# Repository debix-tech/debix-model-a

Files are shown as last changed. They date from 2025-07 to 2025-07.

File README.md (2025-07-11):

# DEBIX Model A Industrial Single Board Computer

<p align="center">
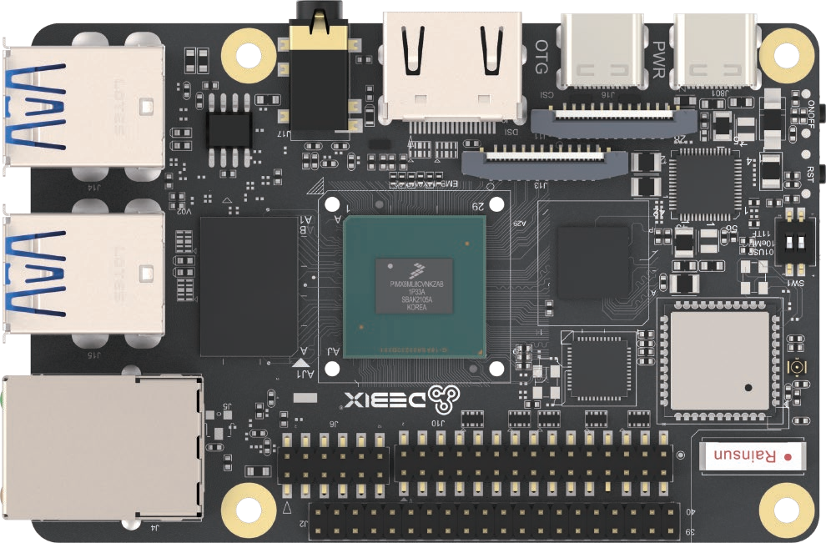
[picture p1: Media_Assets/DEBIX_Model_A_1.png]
DEBIX Model A(1)

</p>

## Overview
DEBIX Model A is an industrial-grade single board computer to bring you faster speed and more powerful performance. Powered by quad core i.MX 8M Plus with 2.3 TOPS NPU, DEBIX Model A with complete software development and rich I/O ports is ready and capable for direct applications in industry 4.0, IoT, smart city, and multimedia.

## Main Features
- **Powerful Performance**  
  Built for demanding industrial applications, DEBIX Model A boasts a quad-core ARM Cortex-A53 CPU up to 1.8GHz and 2GB/4GB/8GB LPDDR4 RAM. This combination ensures smooth operation even for complex processing tasks.
- **Industrial Grade Build**  
  Designed for harsh environments, DEBIX Model A features industrial-grade components and a wide CPU temperature range of -40°C to 105°C. Its DDR inline ECC design and 14 FinFET process further enhance its reliability.
- **Rich Connectivity**  
  DEBIX Model A offers a comprehensive range of connectivity options, including Gigabit Ethernet, 2.4GHz & 5GHz Wi-Fi, Bluetooth 5.0, high-speed USB 3.0, and PCIe support. This allows for easy connection and control of various industrial peripherals.
- **Advanced Multimedia**  
  For multimedia applications, DEBIX Model A features 1080p60 video encode and decode (including H.265 and H.264), 3D/2D graphic acceleration, and multiple audio and voice functionalities.
- **Software Support**  
  It includes Android 11/ Yocto-L6.6.36/ Ubuntu 22.04/ Debian 12/ Windows 10 IoT Enterprise/ OpenWRT/ FreeRTOS operating system and basic software for fast and direct applications.

<p align="center">
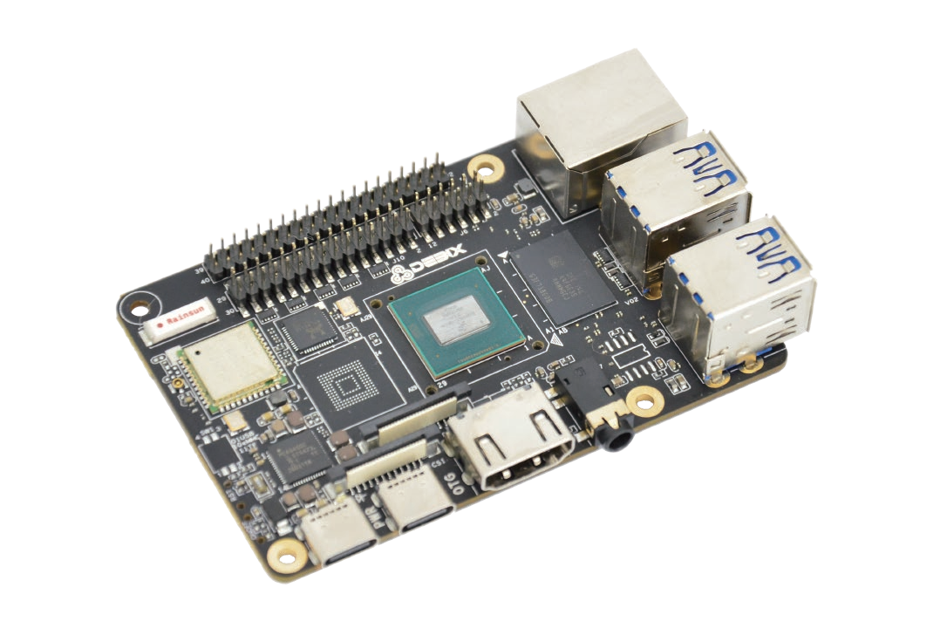
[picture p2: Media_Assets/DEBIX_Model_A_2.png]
DEBIX Model A(2)

</p>

## Specification
| System | |
|---|---|
| CPU | NXP i.MX 8M Plus (default), 4 x ARM Cortex-A53, comes with an integrated neural processing unit (NPU) that delivers up to 2.3 TOPS. Industrial grade CPU runs at 1.6GHz, and commercial grade CPU runs at up to 1.8GHz.(i.MX 8M Plus series CPU optional) |
| Memory | 2GB LPDDR4 (1GB/4GB/8GB optional) |
| Storage | Micro SD card (Onboard 8GB/16GB/32GB/64GB/128GB/256GB eMMC optional) |
| OS | Android 11, Yocto-L6.6.36, Ubuntu 22.04, Debian 12, Win10 IoT Enterprise (also supports OpenWRT and FreeRTOS)<br>*Note: 4GB/8GB RAM required for Win10 IoT, and 8GB RAM is recommended* |
|**I/O Interface**| 
| Gigabit Ethernet| 1 x Gigabit Ethernet, supports TSN and POE power supply (need POE power device module)<br>1 x Gigabit Ethernet via 12pin header (without network transformer) |
| WiFi & BT | 2.4GHz & 5GHz Wi-Fi5, Bluetooth 5.0 |
| USB | 4 x USB 3.0 Host, 1 x USB 2.0 OTG |
| Audio | 1 x Headphone and Mic combo port |
| HDMI | 1 x HDMI OUT |
|**Expansion** |
| 40-Pin Dual-Row Header | (1) 3 x UART, 2 x I2C, 2 x SPI, 2 x CAN, 6 x GPIO for default, can be reused as I2S, PWM, SPDIF and GPIO through software configuration<br>(2) 5V power supply, system reset, ON/OFF |
| LVDS | 1 x LVDS, single/dual channel 8bit |
| MIPI CSI | 1 x MIPI CSI (4-lane) |
| MIPI DSI | 1 x MIPI DSI (4-lane) |
| PCIe | 1 x PCIe Gen3 (1-lane) |
|**Power Supply**|
| Power Supply | DC 5V/3A via Type-C |
|**Mechanical & Environmental**|
| Size | 85.0mm × 56.0mm (±0.5mm) |
| Operating Temp. | -20°C to 70°C |
| Net Weight | 46g (±0.5g) |
| Net Weight | 72g (±0.5g) |

## Product Version
| Version | CPU | NPU | VPU | ISP | HiFi4 |
|--- |-----|-----|-----|-----|---|
| DEBIX Model A Standard | NXP i.MX 8M Plus | 1 | 1 | 1 | 1 |
| DEBIX Model A Lite | NXP i.MX 8M Plus Quad Lite | N/A | N/A | N/A | N/A |

## Certificates:
Certificates

## I/O Interfaces:
<p align="center">
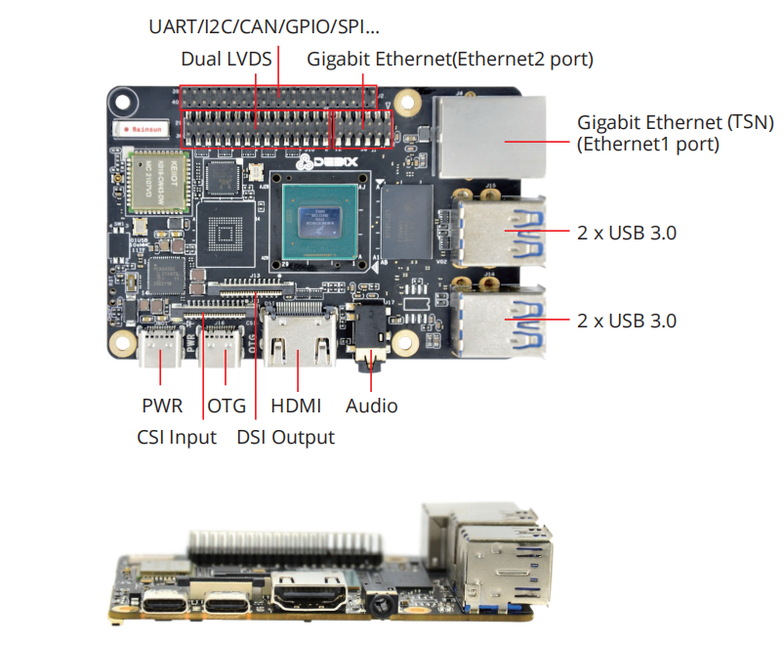
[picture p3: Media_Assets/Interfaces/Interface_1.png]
Interface(1)

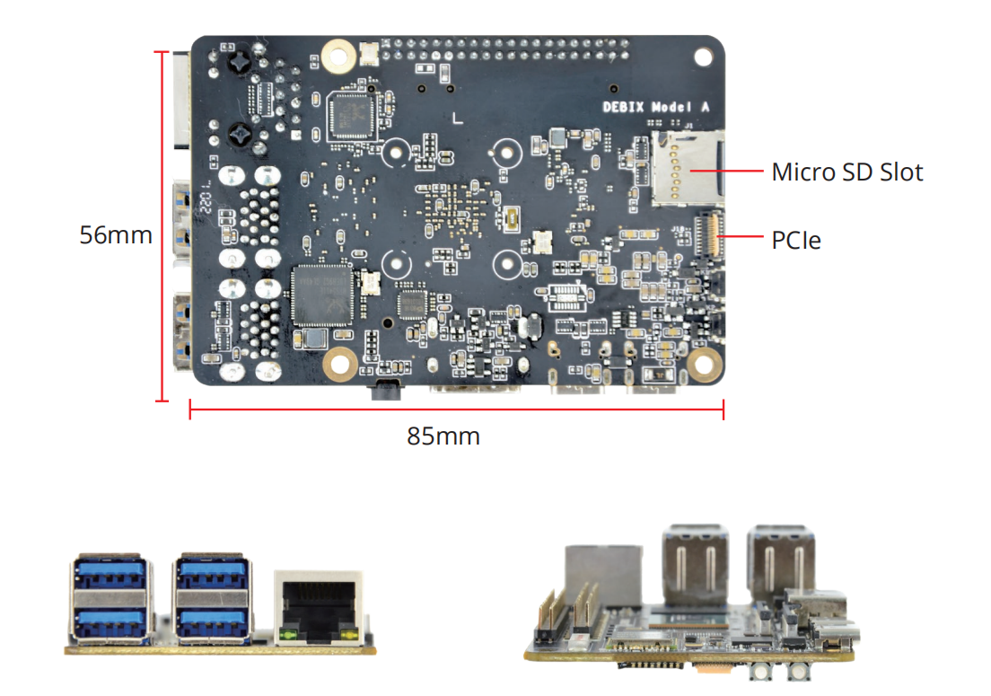
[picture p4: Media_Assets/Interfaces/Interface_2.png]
Interface(2)

</p>

## Ordering Codes
| RAM LPDDR4  | eMMC Storage | PN for Model A | PN for Model A Lite |
|---|---|---|---|
| **1GB DDR** | N/A | Model A-D1E0 | Model A Lite-D1E0 |
| | 8GB | Model A-D1E8 | Model A Lite-D1E8 |
| | 16GB  | Model A-D1E16 | Model A Lite-D1E16 |
| | 32GB  | Model A-D1E32 | Model A Lite-D1E32 |
| | 64GB  | Model A-D1E64 | Model A Lite-D1E64 |
| **2GB DDR** | N/A | Model A-D2E0| Model A Lite-D2E0 |
| | 8GB | Model A-D2E8 | Model A Lite-D2E8 |
| | 16GB  | Model A-D2E16 | Model A Lite-D2E16 |
| | 32GB  | Model A-D2E32 | Model A Lite-D2E32 |
| | 64GB  | Model A-D2E64 | Model A Lite-D2E64 |
| **4GB DDR** | N/A | Model A-D4E0| Model A Lite-D4E0 |
| | 8GB | Model A-D4E8 | Model A Lite-D4E8 |
| | 16GB  | Model A-D4E16 | Model A Lite-D4E16 |
| | 32GB  | Model A-D4E32 | Model A Lite-D4E32 |
| | 64GB  | Model A-D4E64 | Model A Lite-D4E64 |
| **8GB DDR** | N/A | Model A-D8E0| Model A Lite-D8E0 |
| | 8GB | Model A-D8E8 | Model A Lite-D8E8 |
| | 16GB  | Model A-D8E16 | Model A Lite-D8E16 |
| | 32GB  | Model A-D8E32 | Model A Lite-D8E32 |
| | 64GB  | Model A-D8E64 | Model A Lite-D8E64 |

## Compatible with DEBIX's Accessories
| Product | Model |
|---|---|
| DEBIX Fanless Aluminum Enclosure | EMC-7090B Model A/B|
| I/O Board | EMB-AS-E01 |
| 4G Board | EMB-AS-05 |
| LoRa Board | EMB-AS-03 |
| SBC POE Board | EMB-AS-06 |
| DEBIX Camera Modules | Camera 200A; Camera 500A; Camera 1300A |
| DEBIX Display Screens | DEBIX TD050A; DEBIX TD070A; DEBIX TD101A; DEBIX TD050H; DEBIX TD070H; DEBIX TD101H |

## Safety Instructions and Warnings:
**General:**
- Avoid exposure to water, moisture and conductive surfaces while operating.
- Handle with care to avoid mechanical or electrical damage to the circuit board and connectors.
- Only handle the board by the edges when powered on to minimize the risk of electrostatic discharge damage.

**Power:**
- Use only a 5V/3A DC minimum external power supply that complies with relevant regulations and standards for your country.

**Environment:**
- Operate in a well-ventilated environment, even if using a case.
- Place on a stable, flat, non-conductive surface and avoid contact with conductive items.

**Connections:**
- Only connect compatible devices to the GPIO ports to avoid damage and warranty
voiding.
- Use peripherals that comply with relevant standards for the country of use and ensure proper insulation and operation.

**Additional notes:**
- This summary is not exhaustive, please refer to the full User Manual for details.
- If you are unsure about any aspect of safety or operation, consult a qualified
professional.

## Contact Us
- **Headquarters**: DEBIX Technology Inc., 8345 Gold River Ct., Las Vegas, NV 89113, USA  
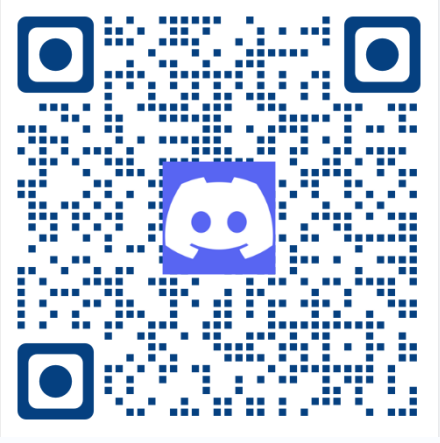
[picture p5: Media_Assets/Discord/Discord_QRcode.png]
Discord(QRcode)
- **Factory**: 5-6/F., East Zone, Shunheda A2 Building, Liqxiandong Industrial Park, XiLi, Nanshan Dist., Shenzhen, China  
- **Email**: info@debix.io  
- **Website**: [www.debix.io](https://www.debix.io)  
- **Community**: [Discord](https://discord.com/invite/adaHHaDkH2)

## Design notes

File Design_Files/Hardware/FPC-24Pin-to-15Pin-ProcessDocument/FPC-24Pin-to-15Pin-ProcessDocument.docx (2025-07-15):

PCB Fabrication Process Engineering Contact Sheet

Project Name (Version) | Polyhex 24PIN-Pai 15PIN V01-20250522-Process Document
Contact Person | | Email | | | Tel
Panelization Method | Non-panelized
Board Thickness | 0.2mm+/-10% | Layer | 2 | Material | FPC (Flexible Printed Circuit)
Board Dimensions | 15*1.6mm
PCB Specifications | 1. ENIG (Electroless Nickel Immersion Gold) Process
| 2. ENIG Copper Thickness: 1 oz
| 3. Coverlay Color: Yellow; Coverlay Thickness: 25μm
| 4. Silkscreen: White
| 5. Compliant with Lead-free & RoHS Requirements
| 6. PI Stiffener Application
| 7. Stiffener Thickness: 0.15mm
Warpage/Twist | IPC 6012 Class 2, ≤0.5%
Packaging | Mark defective boards with "X" on both sides and package separately.
Electrical Testing | Score board edges for passed E-test units.
Unspecified Fabrication Standards | Follow IPC 6012 & 6016 Class 2 for unspecified requirements.

Copper Foil, Stackup, Impedance As per Gerber file data.

PI Stiffener on Gold Finger Backside (FPC Ends)

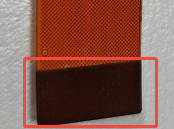
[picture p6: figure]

66 / 92 www.debix.io

Polyhex Technology Company Limited

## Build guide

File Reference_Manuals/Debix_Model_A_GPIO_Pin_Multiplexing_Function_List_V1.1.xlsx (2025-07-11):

Note: | ①Default: Functional definition DEBIX used (Defined in schematics)
 | ②ALT_NAME: alternative function name
Pin | Default | CPU PAD Name | CPU PAD/Pin | ALT0/000 | ALT1/001 | ALT2/010 | ALT3/011 | ALT4/100 | ALT5/101 | ALT6/110
Pin01 | POE_VA1 | - | -
Pin03 | POE_VB1 | - | -
Pin05 | GND | - | -
Pin07 | GND | - | -
Pin09 | UART2_RXD | UART2_RXD | AF6 | UART2_RX | ECSPI3_MISO |  | GPT1_COMPARE3 |  | GPIO5_IO24
Pin11 | UART2_TXD | UART2_TXD | AH4 | UART2_TX | ECSPI3_SS0 |  | GPT1_COMPARE2 |  | GPIO5_IO25
Pin13 | UART3_RXD | UART3_RXD | AE6 | UART3_RX | UART1_CTS_B | USDHC3_RESET_B | GPT1_CAPTURE2 | CAN2_TX | GPIO5_IO26
Pin15 | UART3_TXD | UART3_TXD | AJ4 | UART3_TX | UART1_RTS_B | USDHC3_VSELECT | GPT1_CLK | CAN2_RX | GPIO5_IO27
Pin17 | UART4_RXD | UART4_RXD | AJ5 | UART4_RX | UART2_CTS_B | PCIE_CLKREQ_B | GPT1_COMPARE1 | I2C6_SCL | GPIO5_IO28
Pin19 | UART4_TXD | UART4_TXD | AH5 | UART4_TX | UART2_RTS_B |  | GPT1_CAPTURE1 | I2C6_SDA | GPIO5_IO29
Pin21 | I2C4_SCL | I2C4_SCL | AF8 | I2C4_SCL | PWM2_OUT | PCIE_CLKREQ_B | ECSPI2_MISO |  | GPIO5_IO20
Pin23 | I2C4_SDA | I2C4_SDA | AD8 | I2C4_SDA | PWM1_OUT |  | ECSPI2_SS0 |  | GPIO5_IO21
Pin25 | I2C6_SCL | SAI5_RXFS | AC14 | AUDIOMIX_SAI5_RX_SYNC | AUDIOMIX_SAI1_TX_DATA00 | PWM4_OUT | I2C6_SCL |  | GPIO3_IO19
Pin27 | I2C6_SDA | SAI5_RXC | AD14 | AUDIOMIX_SAI5_RX_BCLK | AUDIOMIX_SAI1_TX_DATA01 | PWM3_OUT | I2C6_SDA | AUDIOMIX_PDM_CLK | GPIO3_IO20
Pin29 | GPIO1_IO11 | GPIO1_IO11 | D8 | GPIO1_IO11 |  | PWM2_OUT |  | USDHC3_VSELECT | CCM_PMIC_READY
Pin31 | CAN1_TXD | SAI5_RXD1 | AD16 | AUDIOMIX_SAI5_RX_DATA01 | AUDIOMIX_SAI1_TX_DATA03 | AUDIOMIX_SAI1_TX_SYNC | AUDIOMIX_SAI5_TX_SYNC | AUDIOMIX_PDM_BIT_STREAM01 | GPIO3_IO22 | CAN1_TX
Pin33 | CAN1_RXD | SAI5_RXD2 | AF16 | AUDIOMIX_SAI5_RX_DATA02 | AUDIOMIX_SAI1_TX_DATA04 | AUDIOMIX_SAI1_TX_SYNC | AUDIOMIX_SAI5_TX_BCLK | AUDIOMIX_PDM_BIT_STREAM02 | GPIO3_IO23 | CAN1_RX
Pin35 | CAN2_TXD | SAI5_RXD3 | AE14 | AUDIOMIX_SAI5_RX_DATA03 | AUDIOMIX_SAI1_TX_DATA05 | AUDIOMIX_SAI1_TX_SYNC | AUDIOMIX_SAI5_TX_DATA00 | AUDIOMIX_PDM_BIT_STREAM03 | GPIO3_IO24 | CAN2_TX
Pin37 | CAN2_RXD | SAI5_MCLK | AF14 | AUDIOMIX_SAI5_MCLK | AUDIOMIX_SAI1_TX_BCLK | PWM1_OUT | I2C5_SDA |  | GPIO3_IO25 | CAN2_RX
Pin39 | GND | - | -
Pin02 | POE_VA2 | - | -
Pin04 | POE_VB2 | - | -
Pin06 | VDD_5V | - | -
Pin08 | VDD_5V | - | -
Pin10 | ONOFF | ONOFF | G22 | snvsmix.ONOFF
Pin12 | SYS_nRST | - | -
Pin14 | ECSPI1_SS0 | ECSPI1_SS0 | AE20 | ECSPI1_SS0 | UART3_RTS_B | I2C2_SDA | AUDIOMIX_SAI7_TX_SYNC |  | GPIO5_IO09
Pin16 | ECSPI1_MOSI | ECSPI1_MOSI | AC20 | ECSPI1_MOSI | UART3_TX | I2C1_SDA | AUDIOMIX_SAI7_RX_BCLK |  | GPIO5_IO07
Pin18 | ECSPI1_MISO | ECSPI1_MISO | AD20 | ECSPI1_MISO | UART3_CTS_B | I2C2_SCL | AUDIOMIX_SAI7_RX_DATA00 |  | GPIO5_IO08
Pin20 | ECSPI1_SCLK | ECSPI1_SCLK | AF20 | ECSPI1_SCLK | UART3_RX | I2C1_SCL | AUDIOMIX_SAI7_RX_SYNC |  | GPIO5_IO06
Pin22 | ECSPI2_SS0 | ECSPI2_SS0 | AJ22 | ECSPI2_SS0 | UART4_RTS_B | I2C4_SDA |  | CCM_CLKO2 | GPIO5_IO13
Pin24 | ECSPI2_MOSI | ECSPI2_MOSI | AJ21 | ECSPI2_MOSI | UART4_TX | I2C3_SDA | AUDIOMIX_SAI7_TX_DATA00 |  | GPIO5_IO11
Pin26 | ECSPI2_MISO | ECSPI2_MISO | AH20 | ECSPI2_MISO | UART4_CTS_B | I2C4_SCL | AUDIOMIX_SAI7_MCLK | CCM_CLKO1 | GPIO5_IO12
Pin28 | ECSPI2_SCLK | ECSPI2_SCLK | AH21 | ECSPI2_SCLK | UART4_RX | I2C3_SCL | AUDIOMIX_SAI7_TX_BCLK |  | GPIO5_IO10
Pin30 | GPIO1_IO12 | GPIO1_IO12 | A5 | GPIO1_IO12 | USB1_PWR |  |  |  | SDMA2_EXT_EVENT01
Pin32 | GPIO1_IO13 | GPIO1_IO13 | A6 | GPIO1_IO13 | USB1_OC |  |  |  | PWM2_OUT
Pin34 | GPIO5_IO03 | SPDIF_TX | AE18 | AUDIOMIX_SPDIF1_OUT | PWM3_OUT | I2C5_SCL | GPT1_COMPARE1 | CAN1_TX | GPIO5_IO03
Pin36 | GPIO5_IO04 | SPDIF_RX | AD18 | AUDIOMIX_SPDIF1_IN | PWM2_OUT | I2C5_SDA | GPT1_COMPARE2 | CAN1_RX | GPIO5_IO04
Pin38 | GPIO3_IO21 | SAI5_RXD0 | AE16 | AUDIOMIX_SAI5_RX_DATA00 | AUDIOMIX_SAI1_TX_DATA02 | PWM2_OUT | I2C5_SCL | AUDIOMIX_PDM_BIT_STREAM00 | GPIO3_IO21
Pin40 | GND | - | -

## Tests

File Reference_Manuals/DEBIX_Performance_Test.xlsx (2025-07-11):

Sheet: DEBIX Model A&B
DEBIX Model A/B Boot from SD Card
Performance Index |  | Andoid12 |  |  | Ubuntu20.04 Desktop |  |  | Ubuntu20.04 server |  |  | Yocto-L5.10.72
 |  | 2GB DDR | 4GB DDR | 8GB DDR | 2GB DDR | 4GB DDR | 8GB DDR | 2GB DDR | 4GB DDR | 8GB DDR | 2GB DDR | 4GB DDR | 8GB DDR
Start-Up Time | uboot startup time | 6s | 5s | 6s | 5s | 5s | 5s | 5s | 5s | 5s | 5s | / | /
 | Kernel startup time | 5s | 5s | 5s | 4s | 5s | 5s | 4s | 5s | 5s | 4s
 | System startup time | 4s | 4s | 4s | 23s | 22s | 22s | 17s | 21s | 17s | 7s
Resource usage | CPU Usage | 0.10% | 2.00% | 0.10% | 1.30% | 1.30% | 0.50% | 0.20% | 0.10% | 0.20% | 0.20%
 | Memory Usage | 55% | 47% | 15% | 42% | 25% | 11% | 24% | 13% | 7% | 25%
 | Storage Capacity | 8GB | 8.66GB | 8.36GB | 3GB | 2.9GB | 2.9GB | 2.8GB | 2.7GB | 2.6GB | 3.4GB
User Experience | System burning time | 4:00 | 3:50 | 4:03 | 2:10 | 2:12 | 2:13 | 2:10 | 2:12 | 2:13 | 2:43
 | Video Effects | 720P: 60FPS, 1080P: 60FPS, 2K/4K: not supported
 | Application Response Time | Command Response: ms level, Chrome: 2s,Terminal: 1s
DEBIX Model A/B Boot from eMMC
Performance Index |  | Andoid12 |  |  | Ubuntu20.04 Desktop |  |  | Ubuntu20.04 server |  |  | Yocto-L5.10.72
 |  | 2GB DDR | 4GB DDR | 8GB DDR | 2GB DDR | 4GB DDR | 8GB DDR | 2GB DDR | 4GB DDR | 8GB DDR | 2GB DDR | 4GB DDR | 8GB DDR
Start-Up Time | uboot startup time | 5s | 5s | 5s | 4s | 4s | 3s | 4s | 4s | 4s | / | / | /
 | Kernel startup time | 5s | 5s | 5s | 5s | 5s | 5s | 4s | 5s | 5s
 | System startup time | 4s | 4s | 4s | 17s | 22s | 18s | 21s | 20s | 16s
Resource Usage | CPU Usage | 0.10% | 0.30% | 0.10% | 0.20% | 0.20% | 0.20% | 0.20% | 0.20% | 0.20%
 | Memory Usage | 52% | 32% | 15% | 40% | 25% | 10% | 23% | 13% | 7%
 | Storage Capacity | 7.63GB | 7.93GB | 8.71GB | 2.8GB | 2.9GB | 2.7GB | 2.7GB | 2.7GB | 2.5GB
User Experience | System burning time | 2:11 | 3:00 | 2:12 | 7:48 | 7:27 | 8:00 | 7:48 | 7:27 | 8:00
 | Video Effects | 720P: 60FPS, 1080P: 60FPS, 2K/4K: not supported
 | Application Response Time | Command Response: ms level, Chrome: 2s, Terminal: 1s

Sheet: DEBIX SOM A
DEBIX SOM A Boot from SD Card
Performance Index |  | Andoid12 |  |  | Ubuntu20.04 Desktop |  |  | Ubuntu20.04 server |  |  | Yocto-L5.10.72
 |  | 2GB DDR | 4GB DDR | 8GB DDR | 2GB DDR | 4GB DDR | 8GB DDR | 2GB DDR | 4GB DDR | 8GB DDR | 2GB DDR | 4GB DDR | 8GB DDR
Start-Up Time | uboot startup time | 6s | 5s | 6s | 5s | 5s | 5s | 5s | 5s | 5s | / | / | /
 | Kernel startup time | 4s | 5s | 5s | 5s | 5s | 6s | 5s | 5s | 5s
 | System startup time | 4s | 4s | 4s | 18s | 18s | 22s | 22s | 22s | 22s
Resource usage | CPU Usage | 0.40% | 0.90% | 0.80% | 0.20% | 0.70% | 0.20% | 0.30% | 0.20% | 0.20%
 | Memory Usage | 51% | 35% | 15% | 40% | 21% | 13% | 24% | 13% | 7%
 | Storage Capacity | 8.4GB | 7.4GB | 7.88GB | 2.8GB | 2.7GB | 2.7GB | 2.5GB | 2.4GB | 2.4GB
User Experience | System burning time | 4:10 | 4:12 | 4:45 | 2:10 | 2:12 | 2:13 | 2:10 | 2:12 | 2:13
 | Video Effects | 720P: 60FPS, 1080P: 60FPS, 2K/4K: not supported
 | Application Response Time | Command Response: ms level, Chrome: 2s,Terminal: 1s
DEBIX SOM A Boot from eMMC
Performance Index |  | Andoid12 |  |  | Ubuntu20.04 Desktop |  |  | Ubuntu20.04 server |  |  | Yocto-L5.10.72
 |  | 2GB DDR | 4GB DDR | 8GB DDR | 2GB DDR | 4GB DDR | 8GB DDR | 2GB DDR | 4GB DDR | 8GB DDR | 2GB DDR | 4GB DDR | 8GB DDR
Start-Up Time | uboot startup time | 5s | 5s | 5s | 3s | 3s | 4s | 4s | 3s | 3s | 4s | 3s | 4s
 | Kernel startup time | 5s | 5s | 5s | 5s | 5s | 5s | 4s | 5s | 5s | 5s | 5s | 5s
 | System startup time | 3s | 4s | 3s | 17s | 17s | 17s | 17s | 12s | 17s | 6s | 7s | 6s
Resource usage | CPU Usage | 1% | 0.40% | 0.60% | 0.20% | 0.60% | 0.20% | 0.20% | 0.30% | 0.20% | 0.20% | 0.70% | 0.20%
 | Memory Usage | 51% | 35% | 16% | 40% | 21% | 10% | 24% | 13% | 7% | 25% | 13% | 6.50%
 | Storage Capacity | 7.5GB | 8.28GB | 8.78GB | 2.7GB | 2.7GB | 2.7GB | 2.4GB | 2.4GB | 2.4GB | 3.4GB | 3.4GB | 3.4G
User Experience | System Burning Time | 3:15 | 3:04 | 3:05 | 7:55 | 8:27 | 6:55 | 7:55 | 8:27 | 6:55 | 11:32 | 11:39 | 11:25
 | Video Effects | 720P: 60FPS, 1080P: 60FPS, 2K/4K: not supported
 | Application Response Time | Command Response: ms level, Chrome: 2s, Terminal: 1s

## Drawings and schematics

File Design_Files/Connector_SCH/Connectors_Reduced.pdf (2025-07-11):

5

4

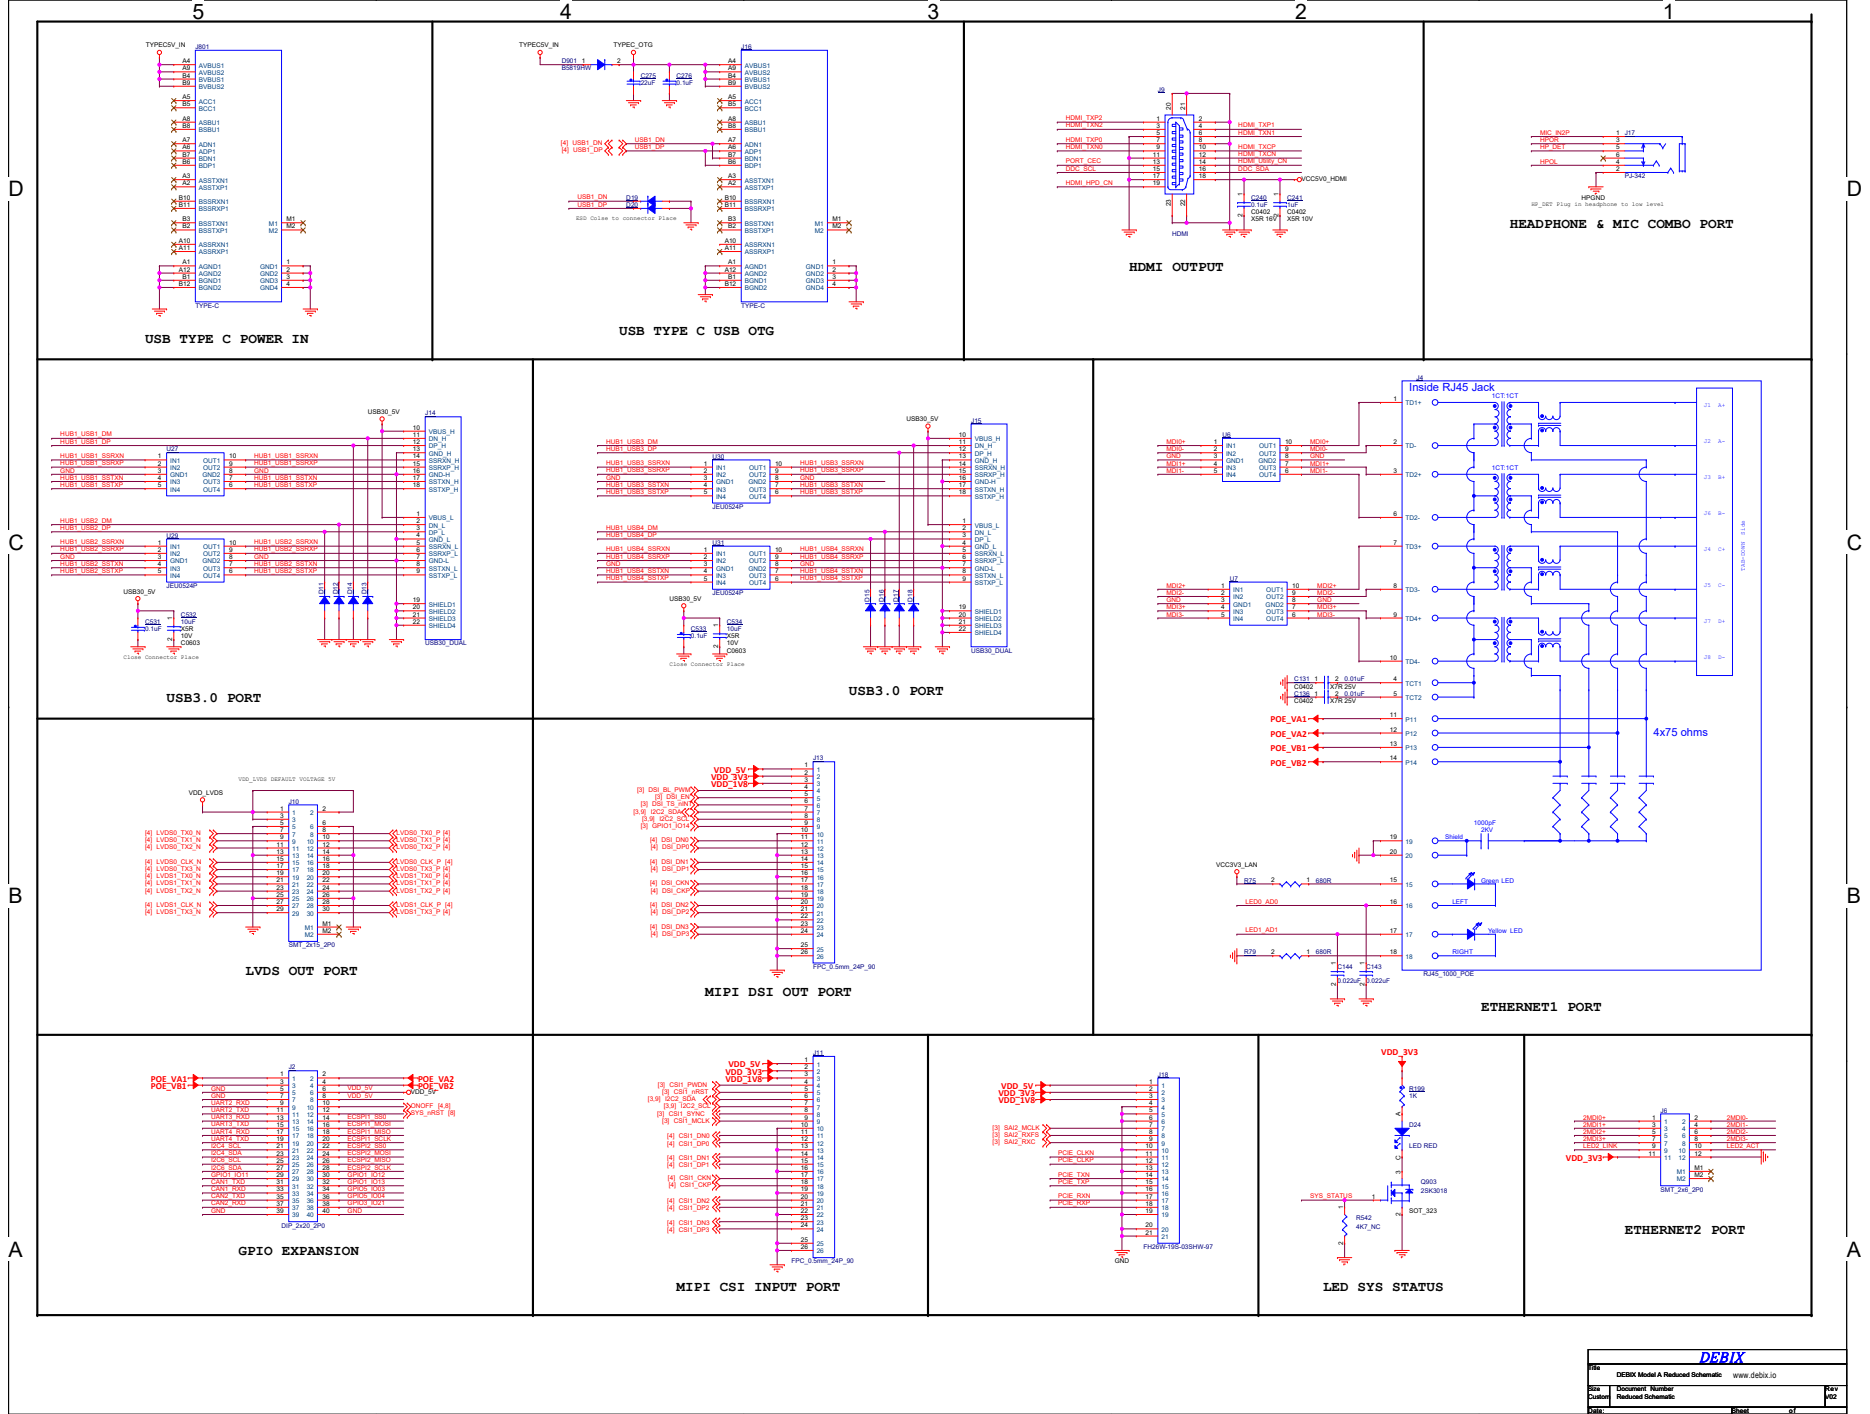
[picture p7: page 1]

ESD Colse to connector Place

HP_DET Plug in headphone to low level
HEADPHONE & MIC COMBO PORT

MIPI DSI OUT PORT

MIPI CSI INPUT PORT

DEBIX Model A Reduced Schematic

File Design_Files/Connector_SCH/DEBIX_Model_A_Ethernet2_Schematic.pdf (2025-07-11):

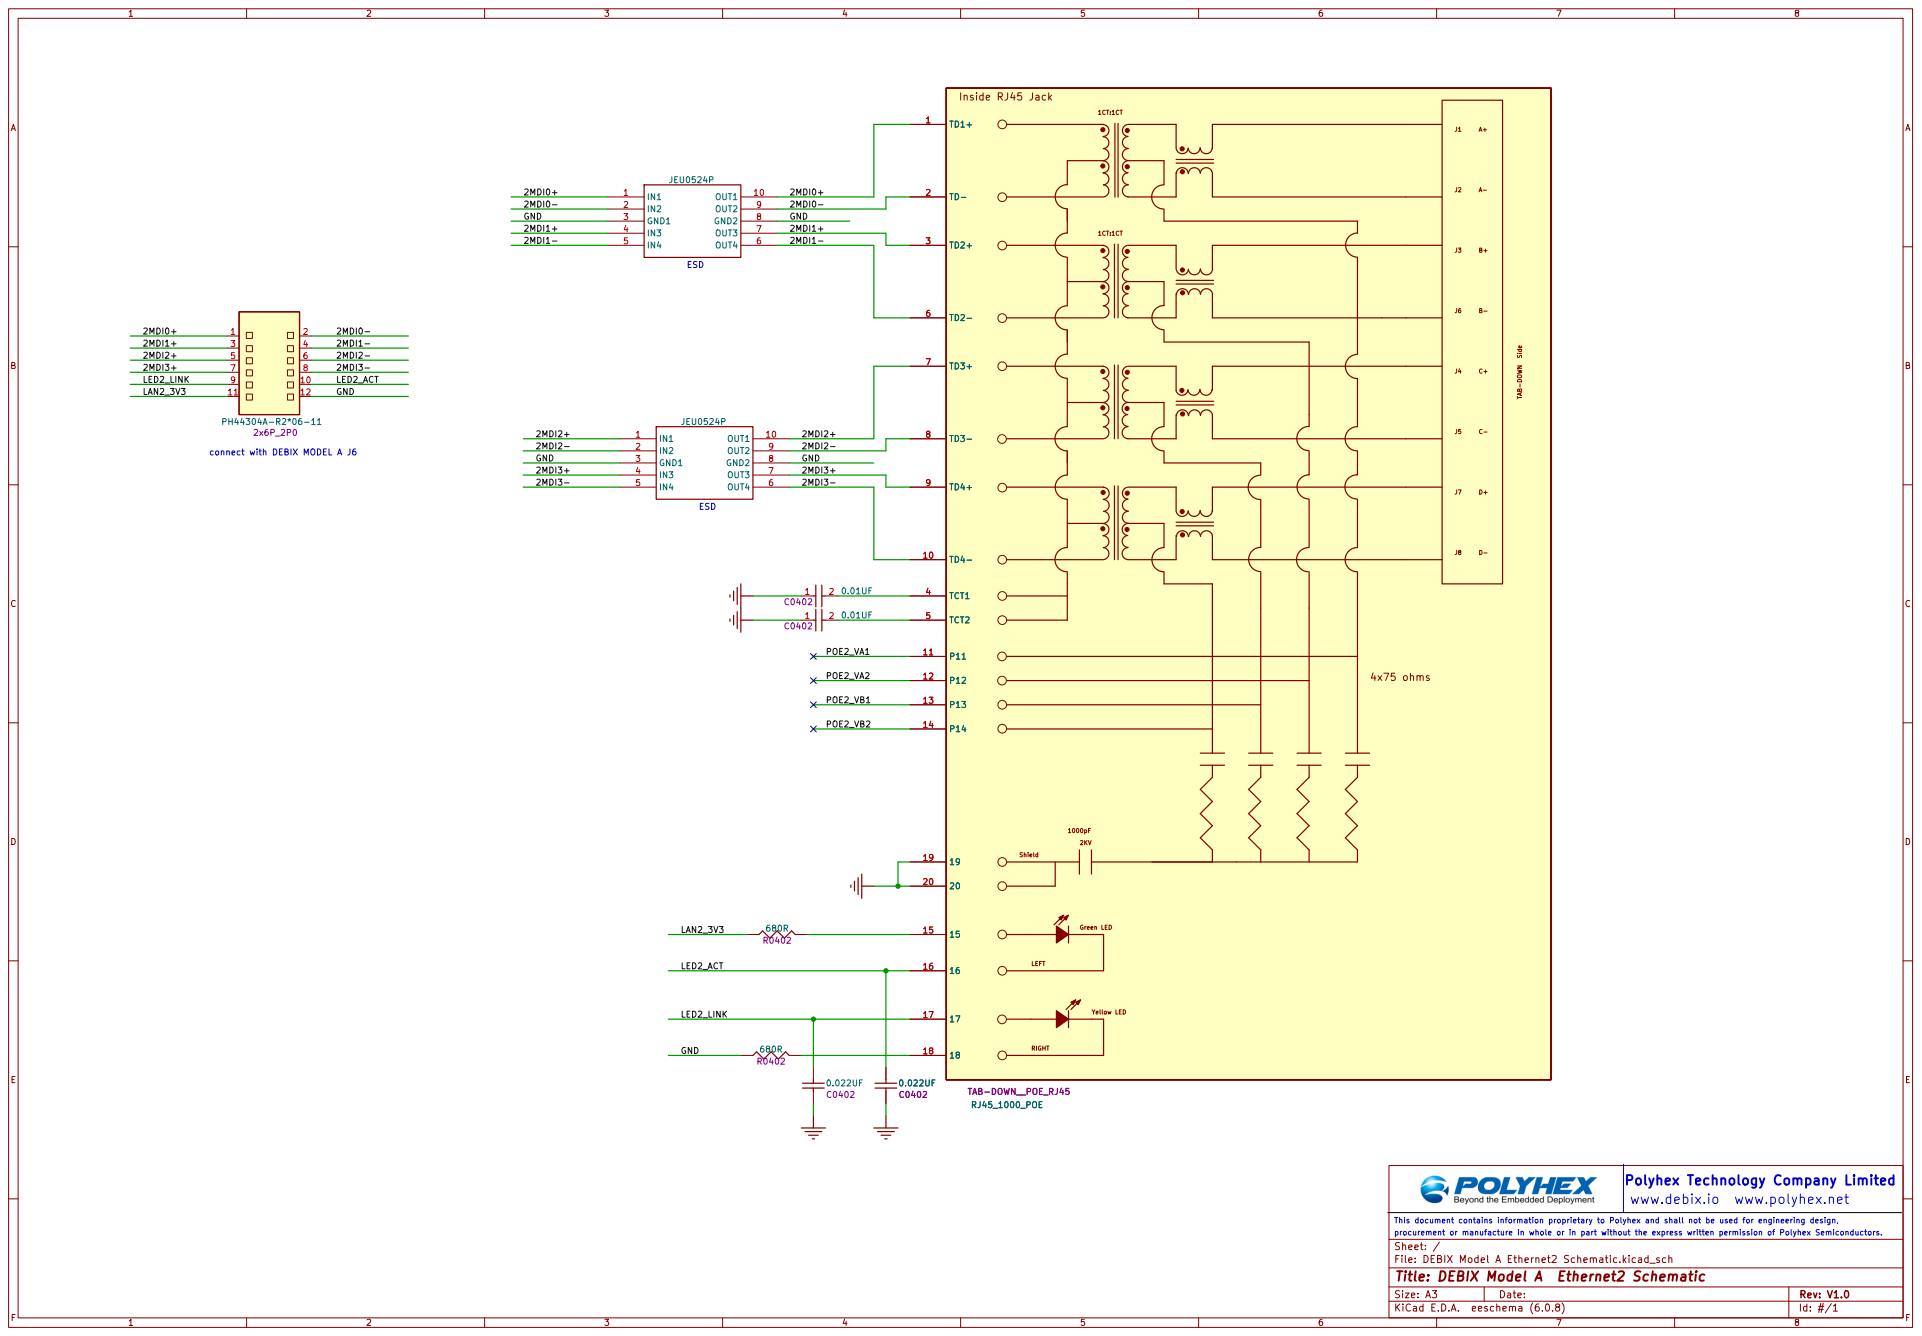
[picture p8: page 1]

File: DEBIX Model A Ethernet2 Schematic.kicad_sch Sheet: /
Id: #/1 Title: DEBIX Model A Ethernet2 Schematic

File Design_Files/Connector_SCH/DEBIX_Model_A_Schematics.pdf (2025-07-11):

# i.MX8M Plus PWR

## NVCC_SNVS_1V8

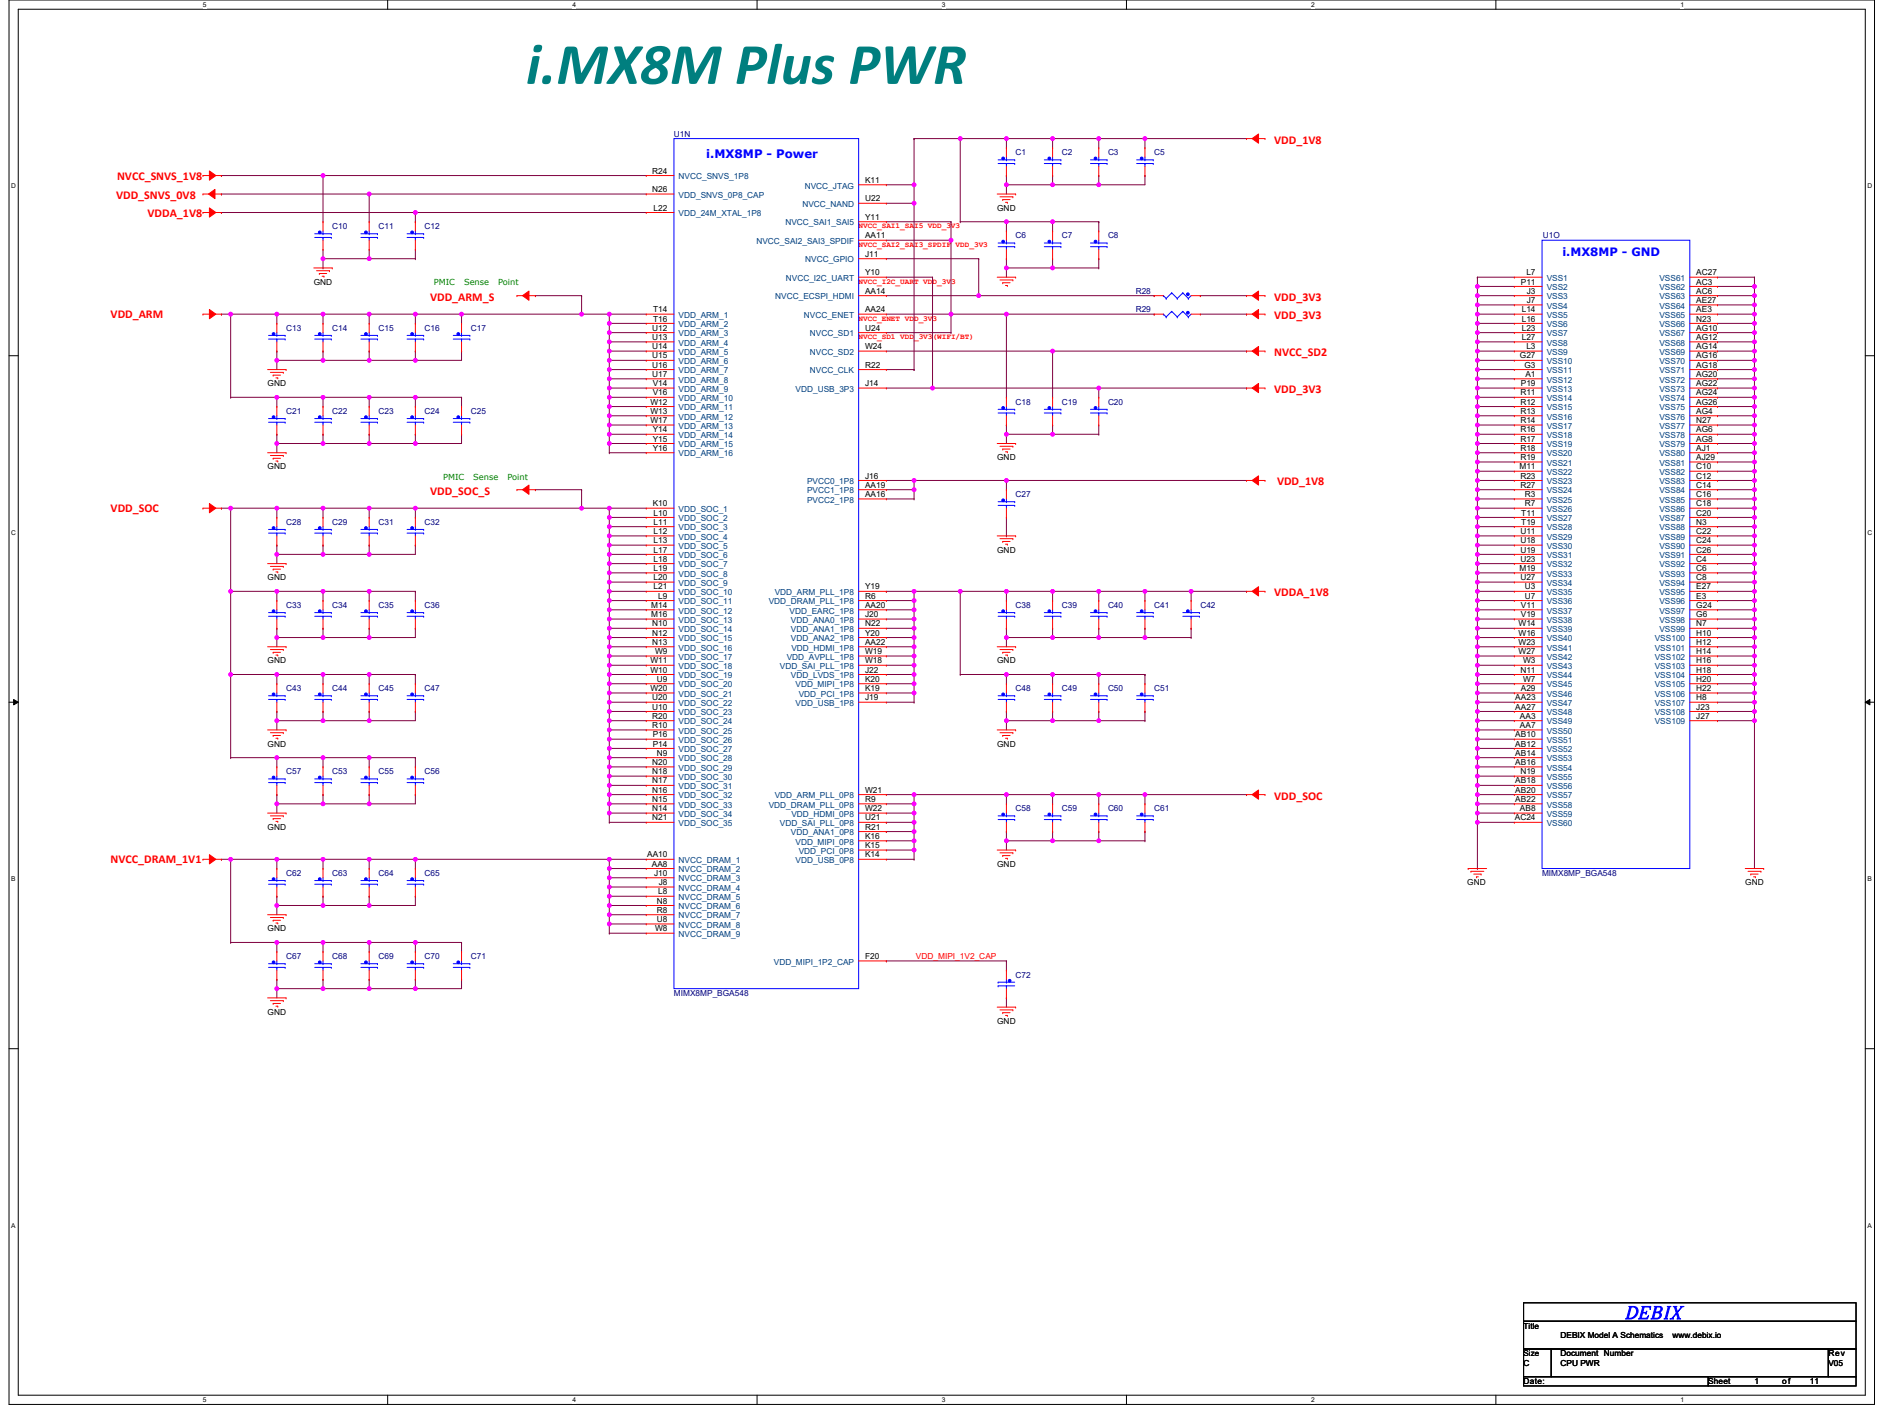
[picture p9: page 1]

DEBIX Model A Schematics www.debix.io

# i.MX8M Plus IO Interface

# eMMC5.1

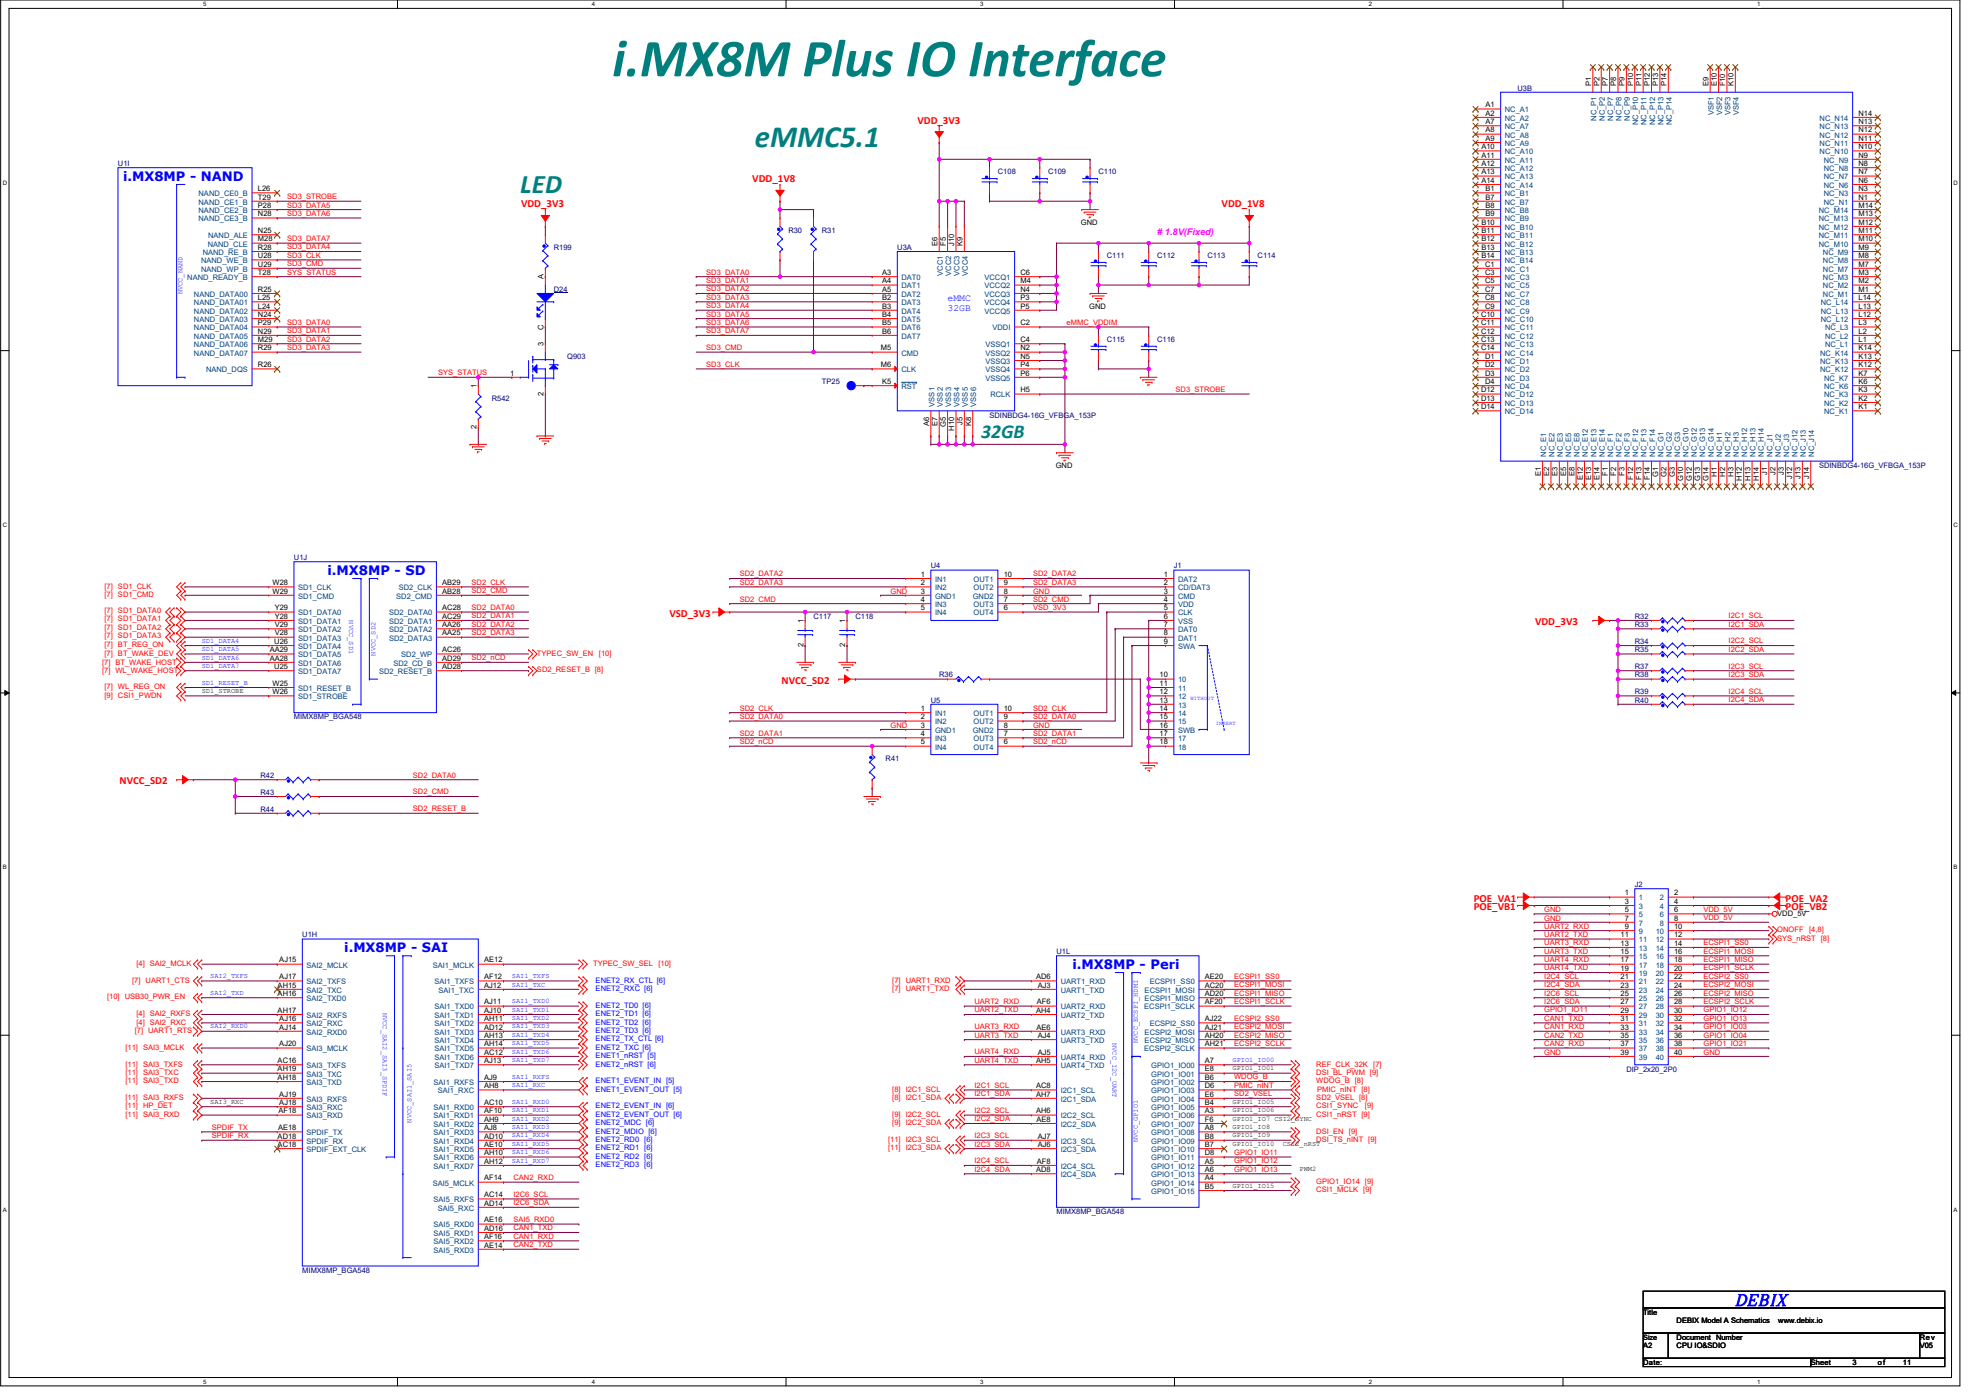
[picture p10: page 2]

# i.MX8M Plus PHYs MISC

## NVCC_SNVS_1V8

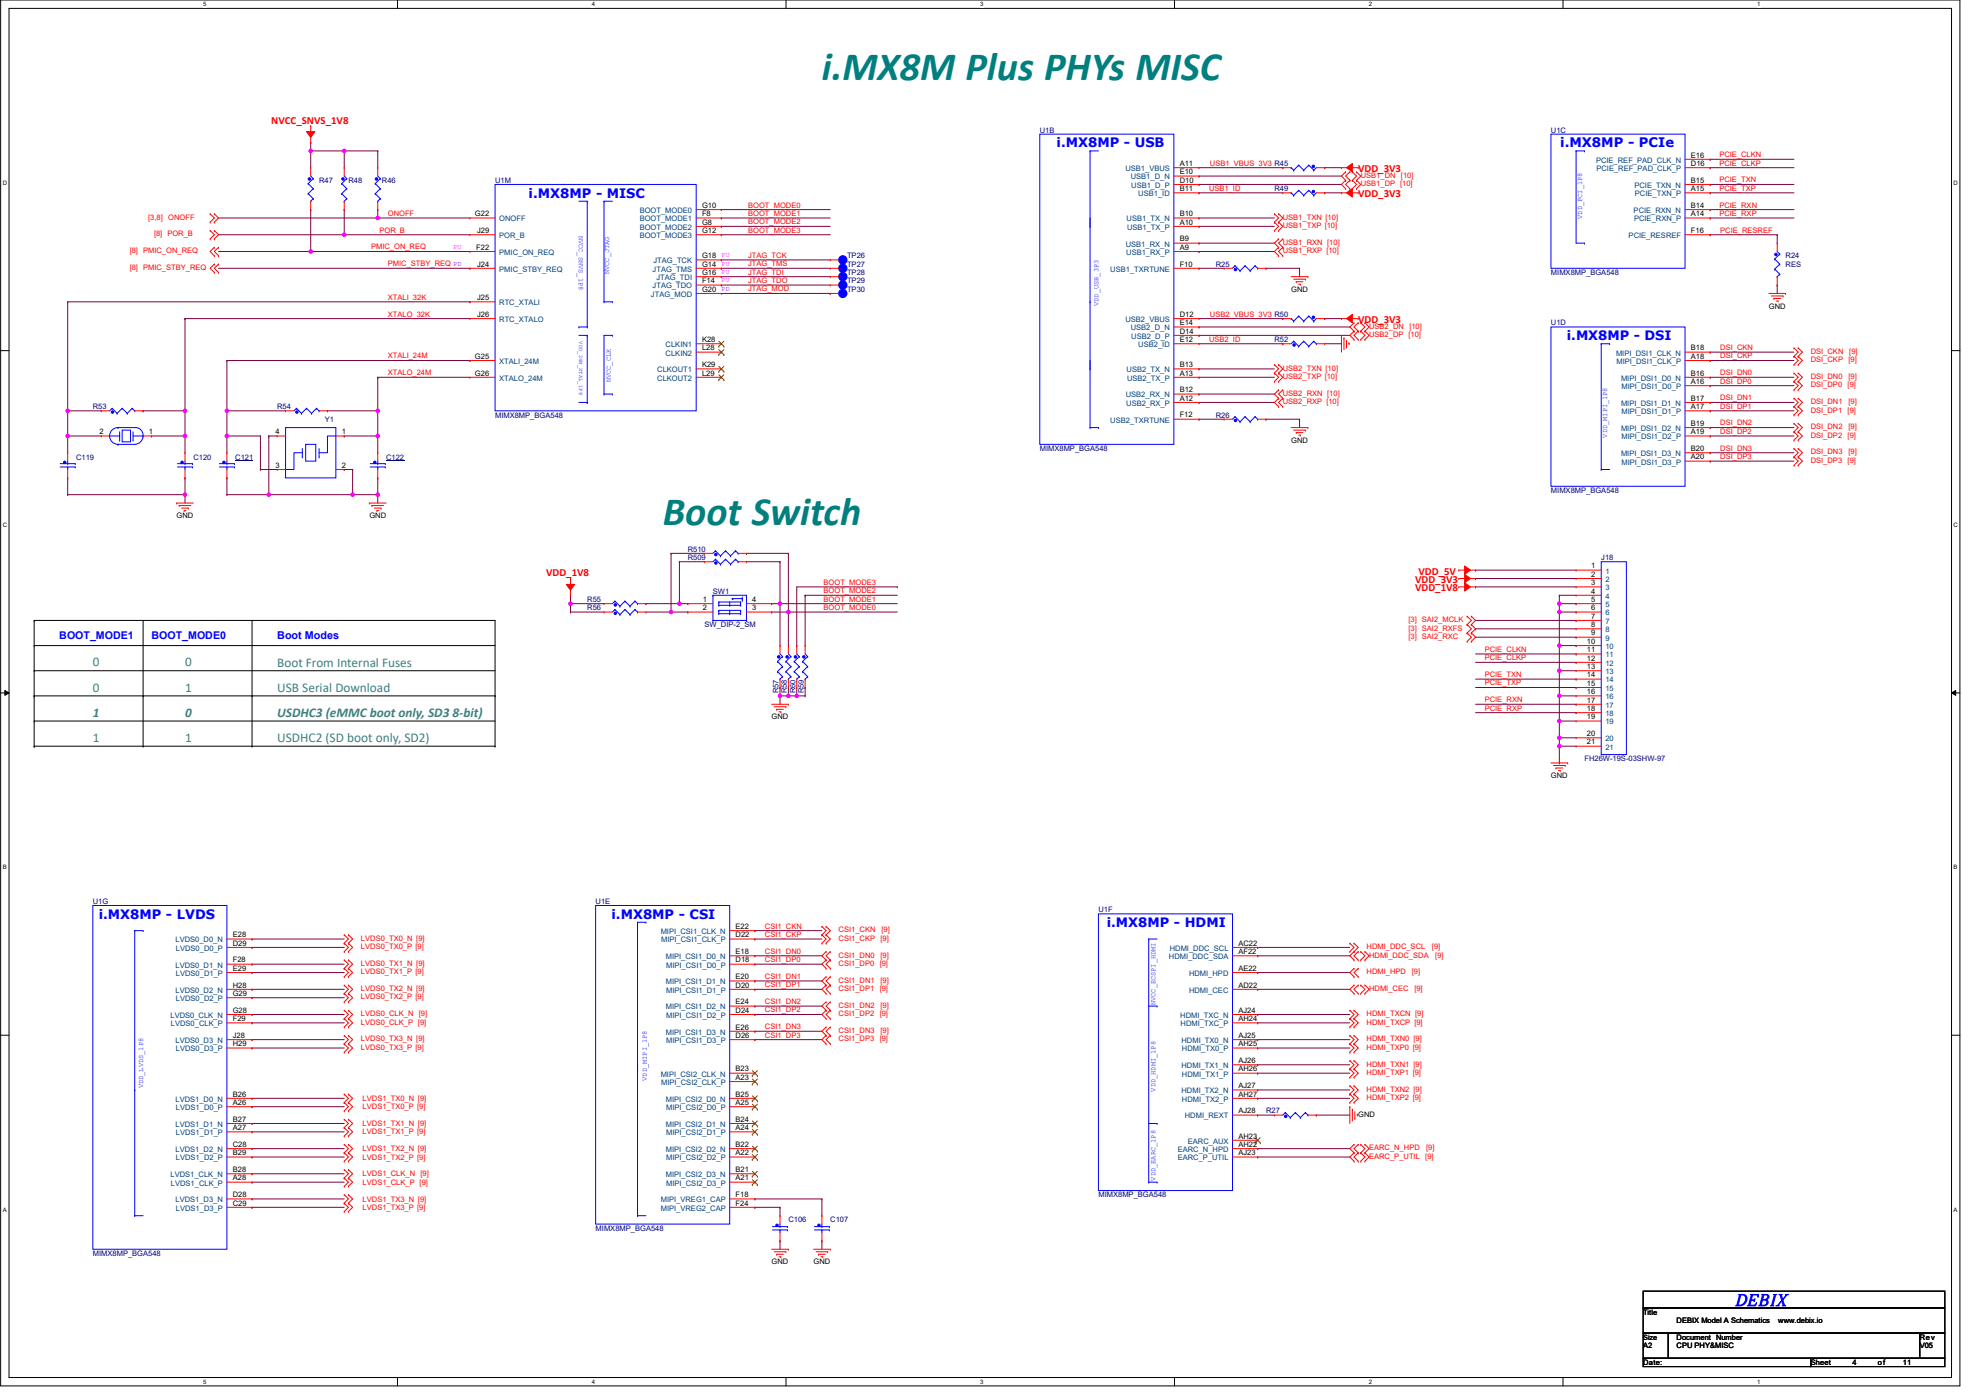
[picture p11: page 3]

# Inside RJ45 Jack

## i.MX8MP - eNET

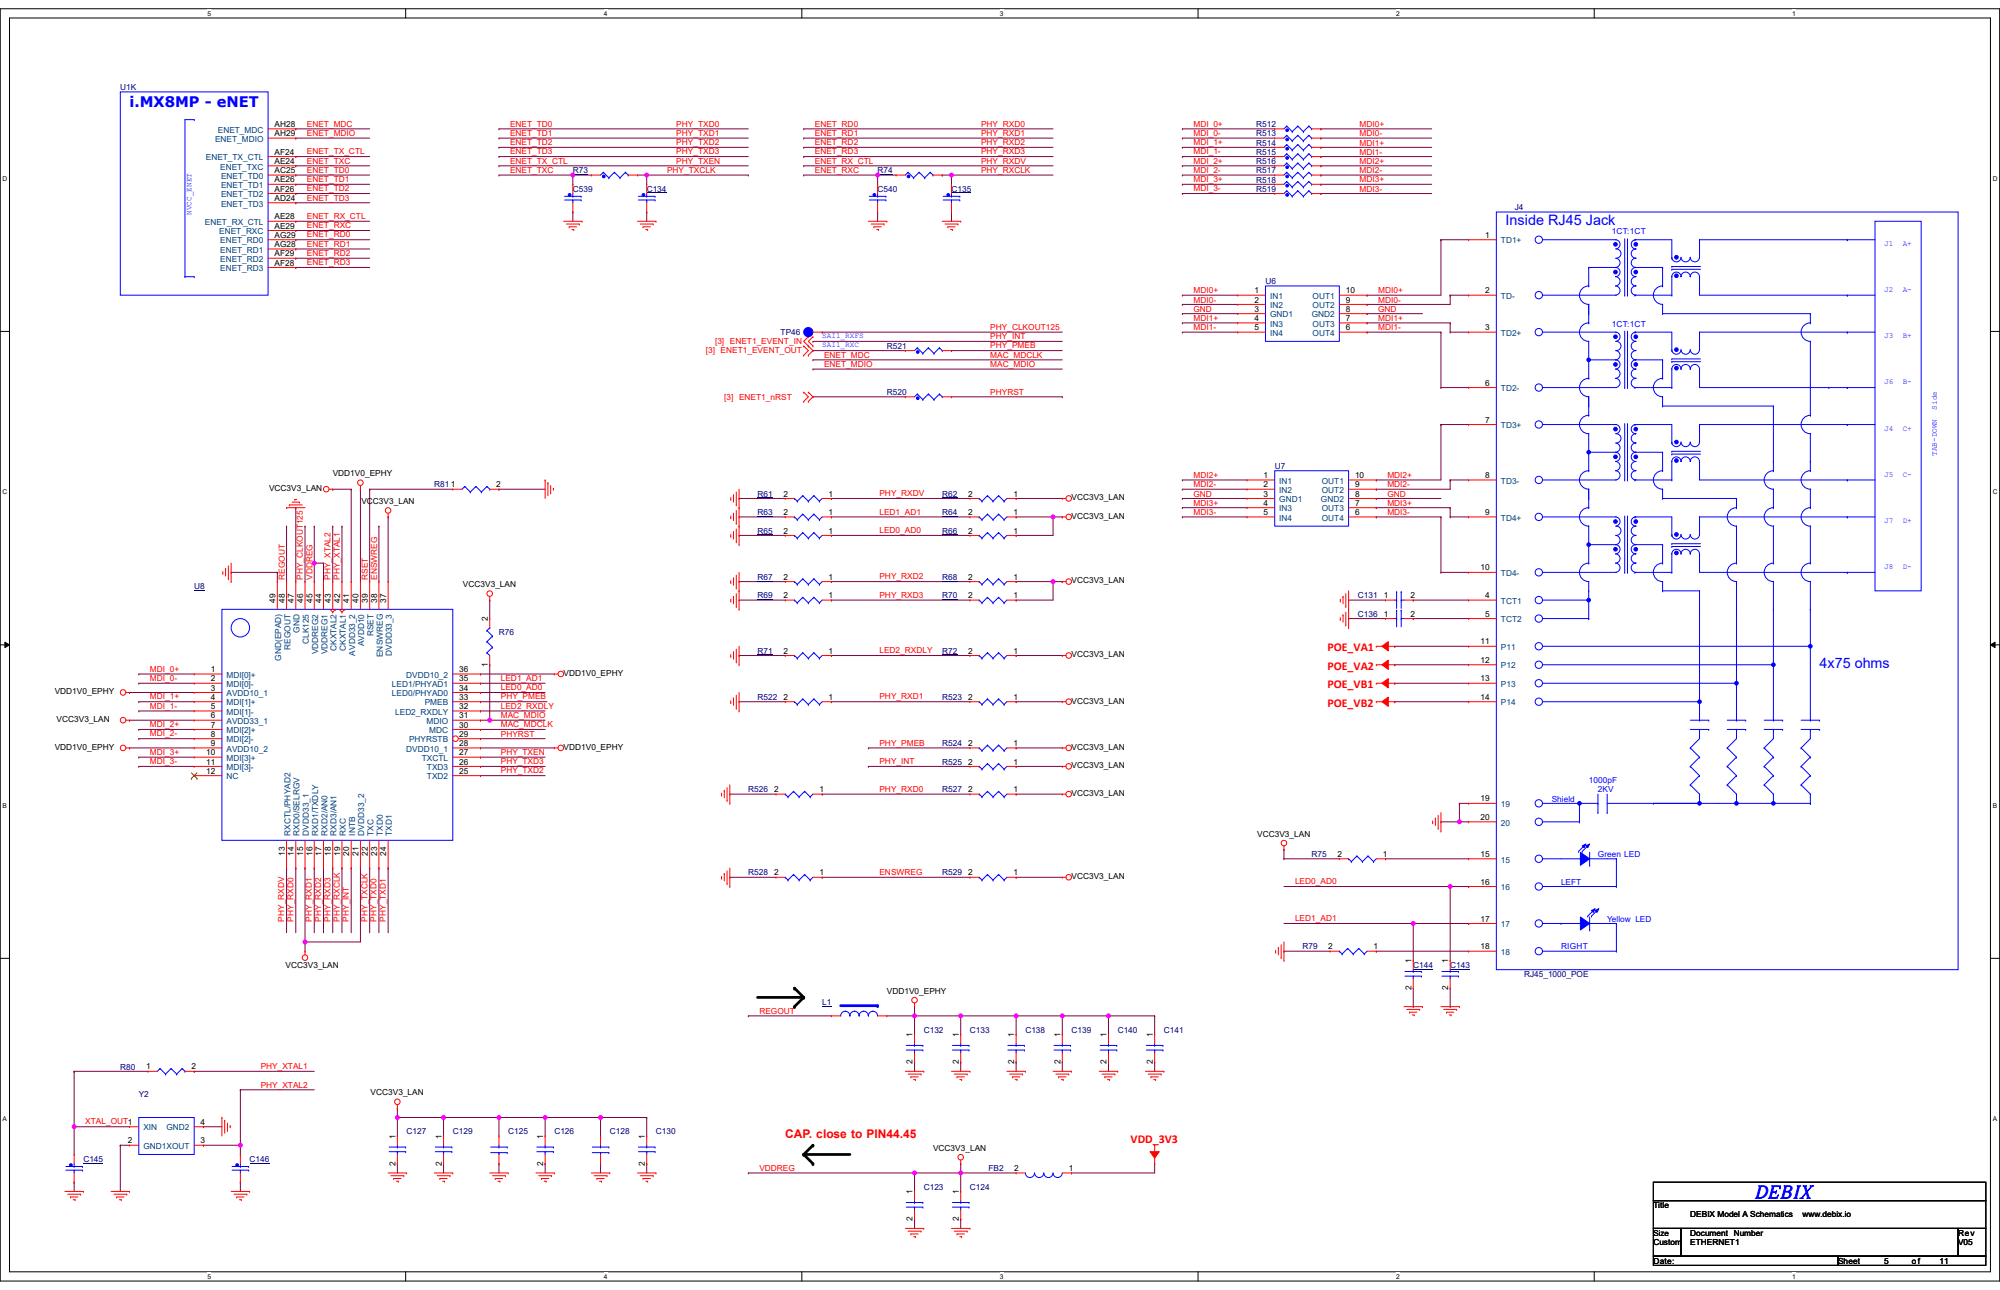
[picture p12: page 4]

DEBIX Model A Schematics www.debix.io

## 2MDI0+ 2MDI1+

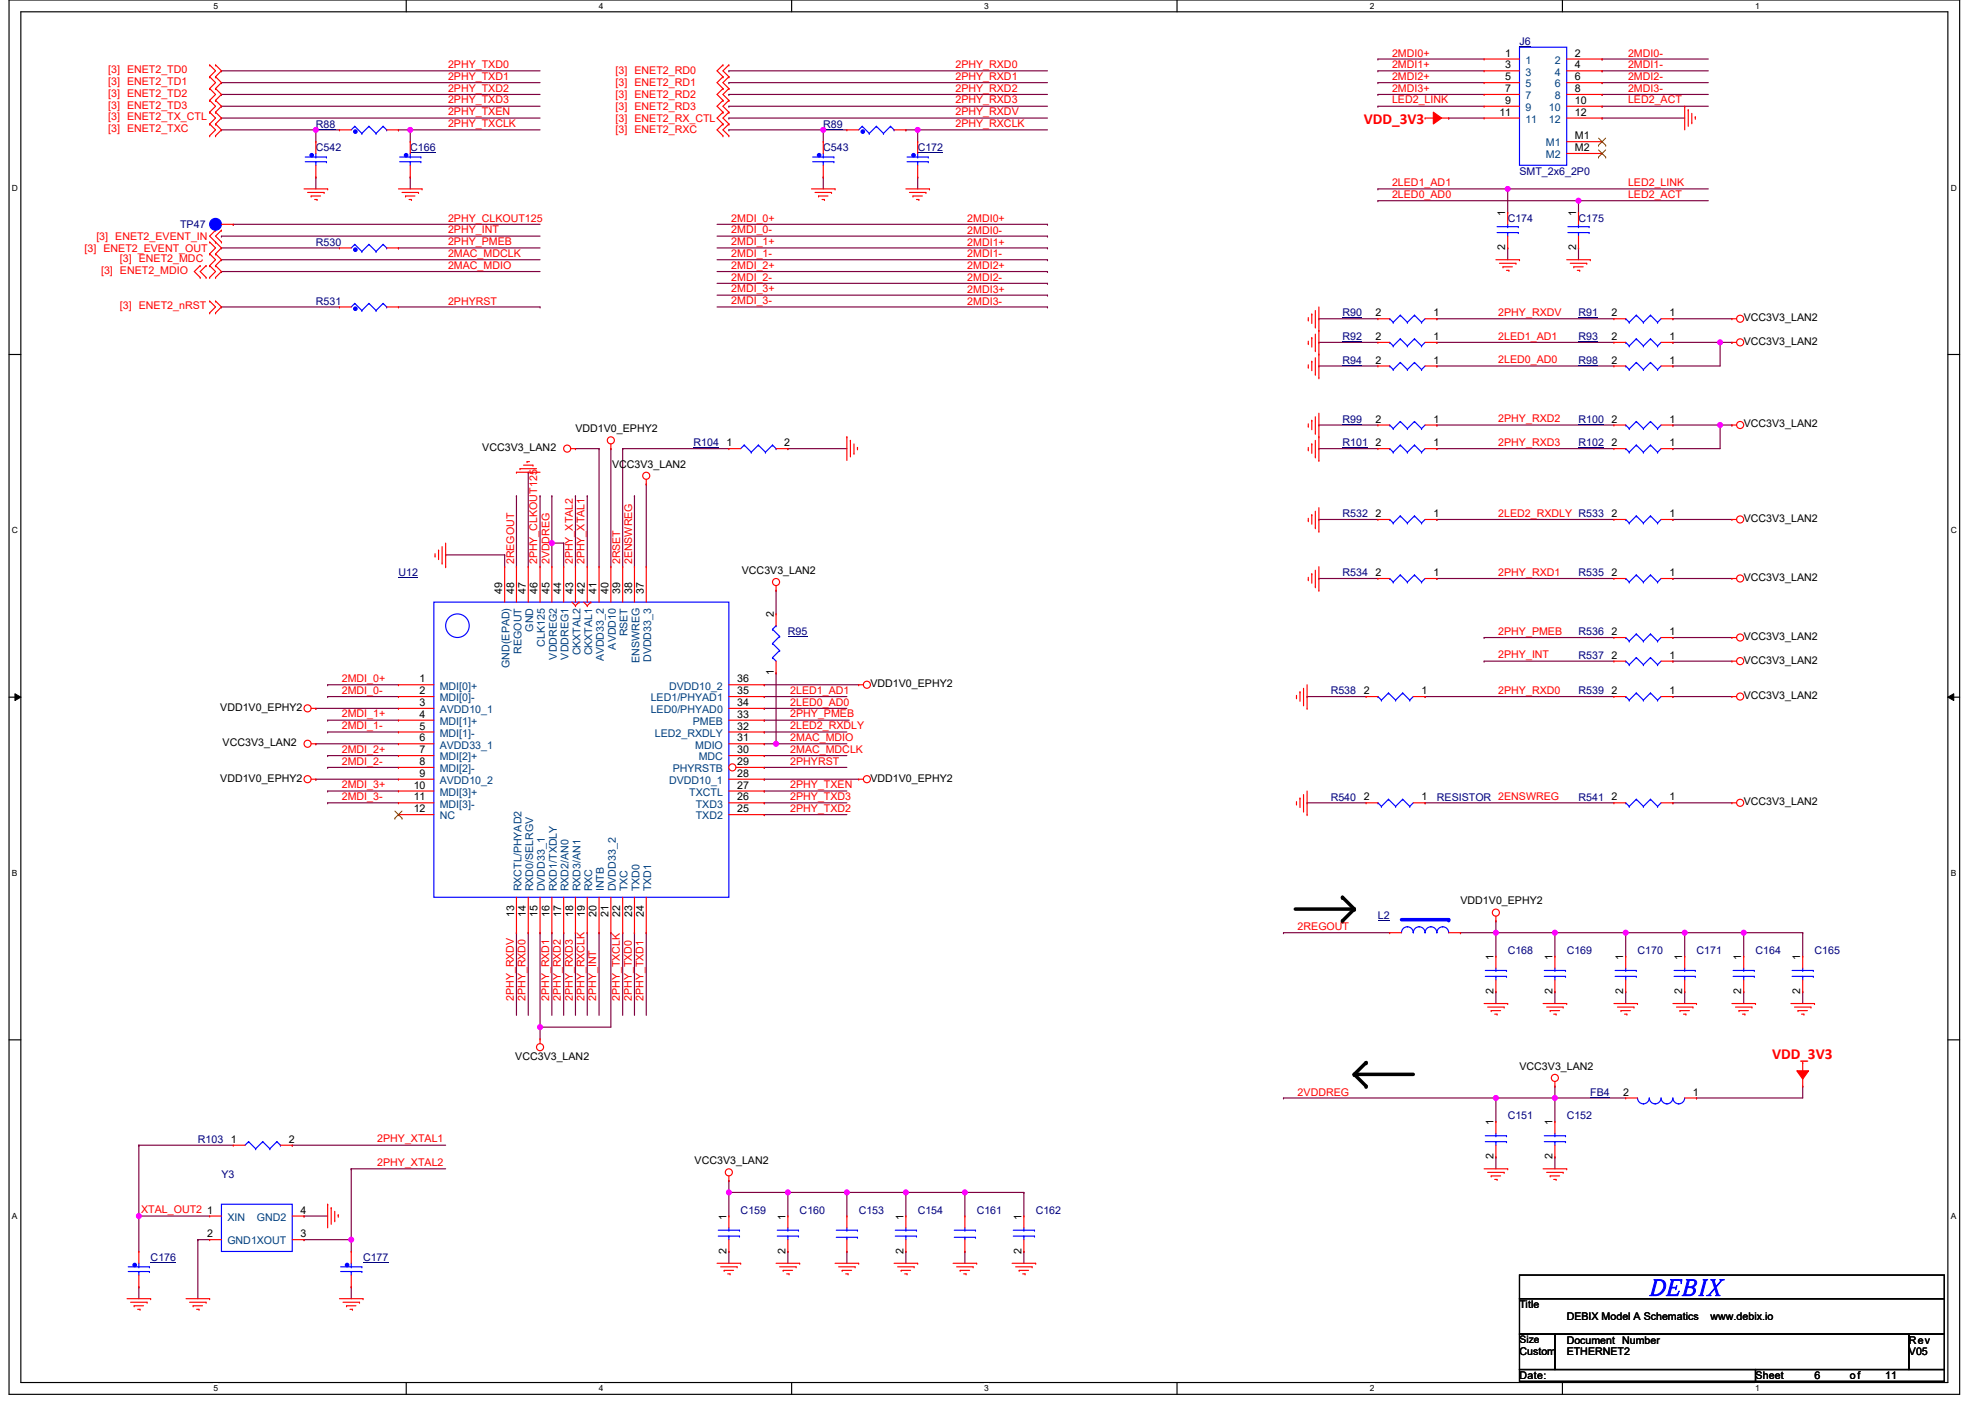
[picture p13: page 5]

D D

# SDIO WIFI/BT MODULE 2.4G/5G

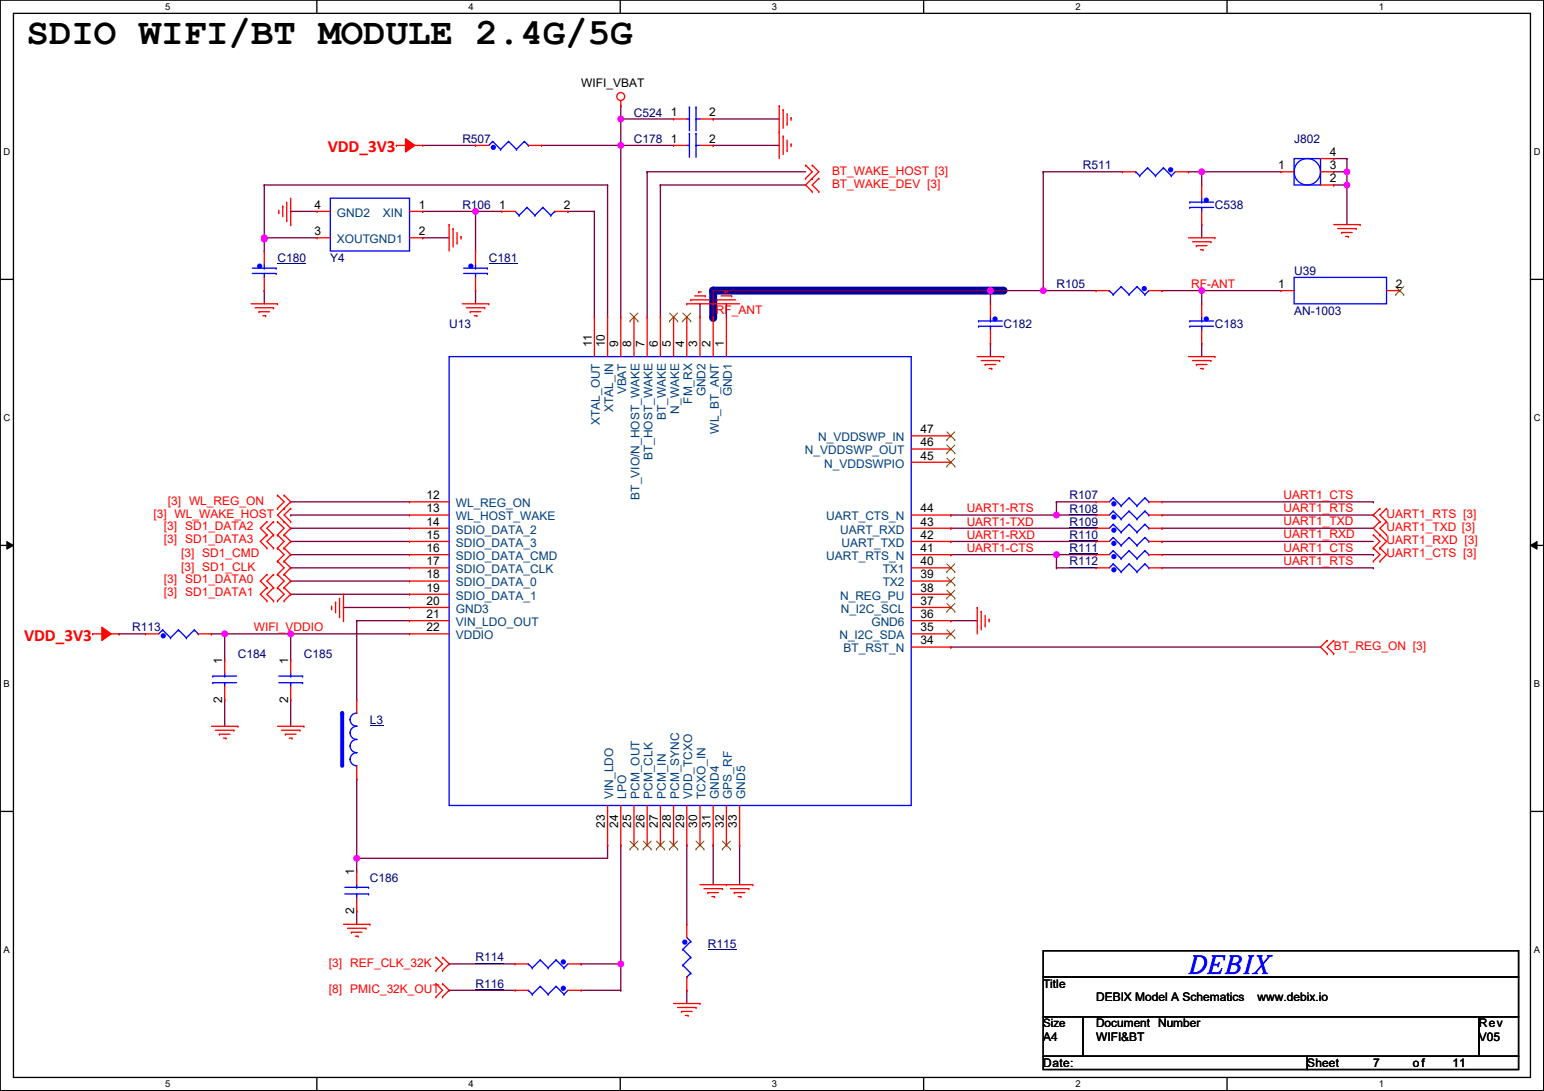
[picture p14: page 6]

DEBIX Model A Schematics www.debix.io

# SYS PMIC

## VSYS_5V

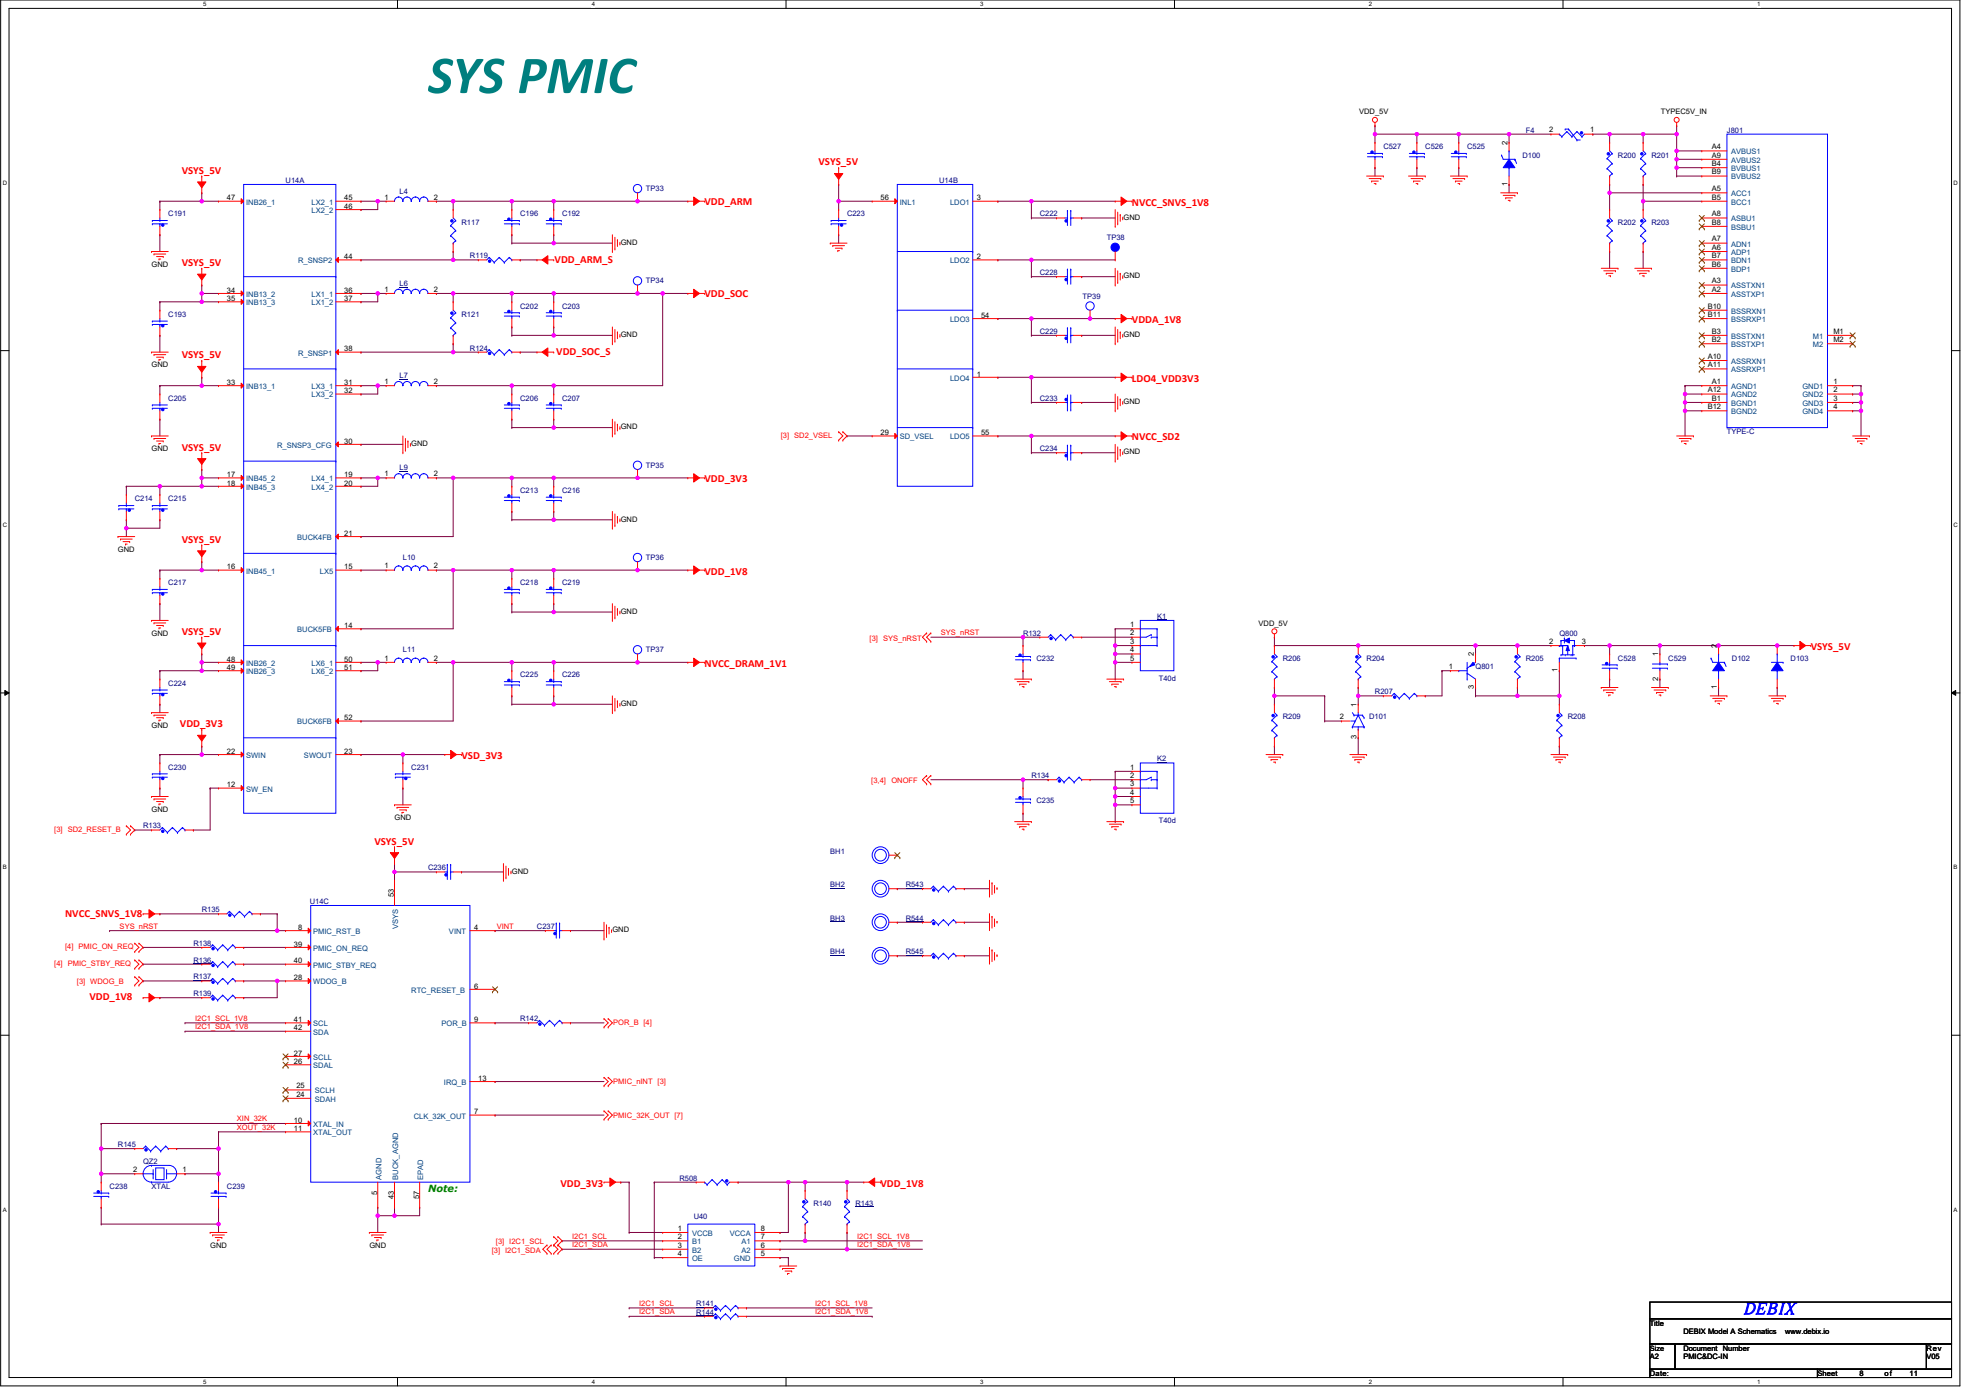
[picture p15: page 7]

HDMI OUT | DUAL LVDS OUT

## VDD_3V3

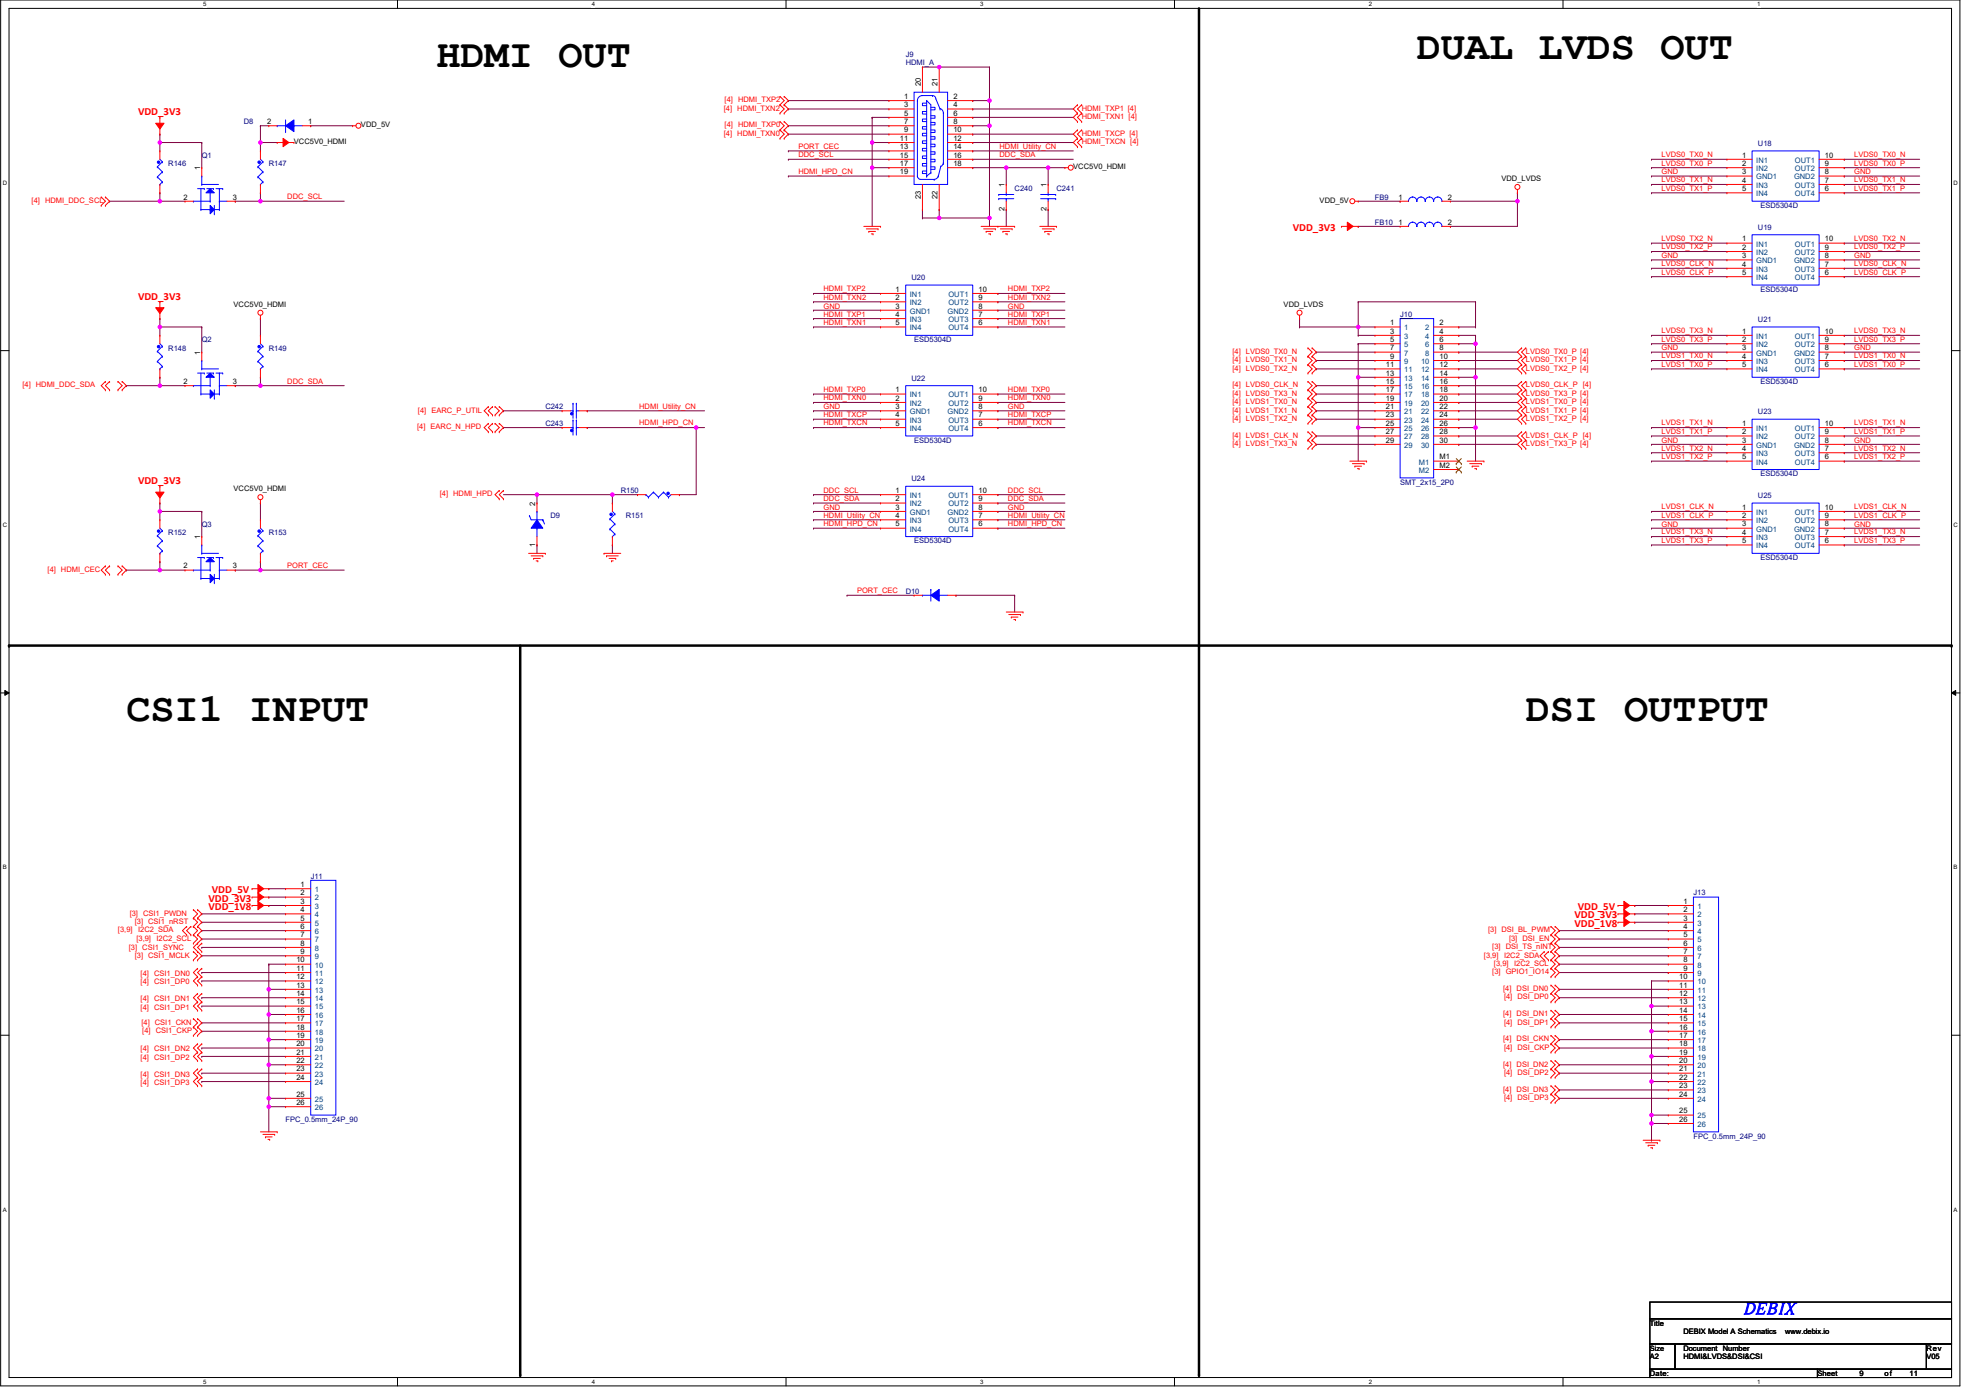
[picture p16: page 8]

## SWR_5V_IN

## LDO_5V_IN

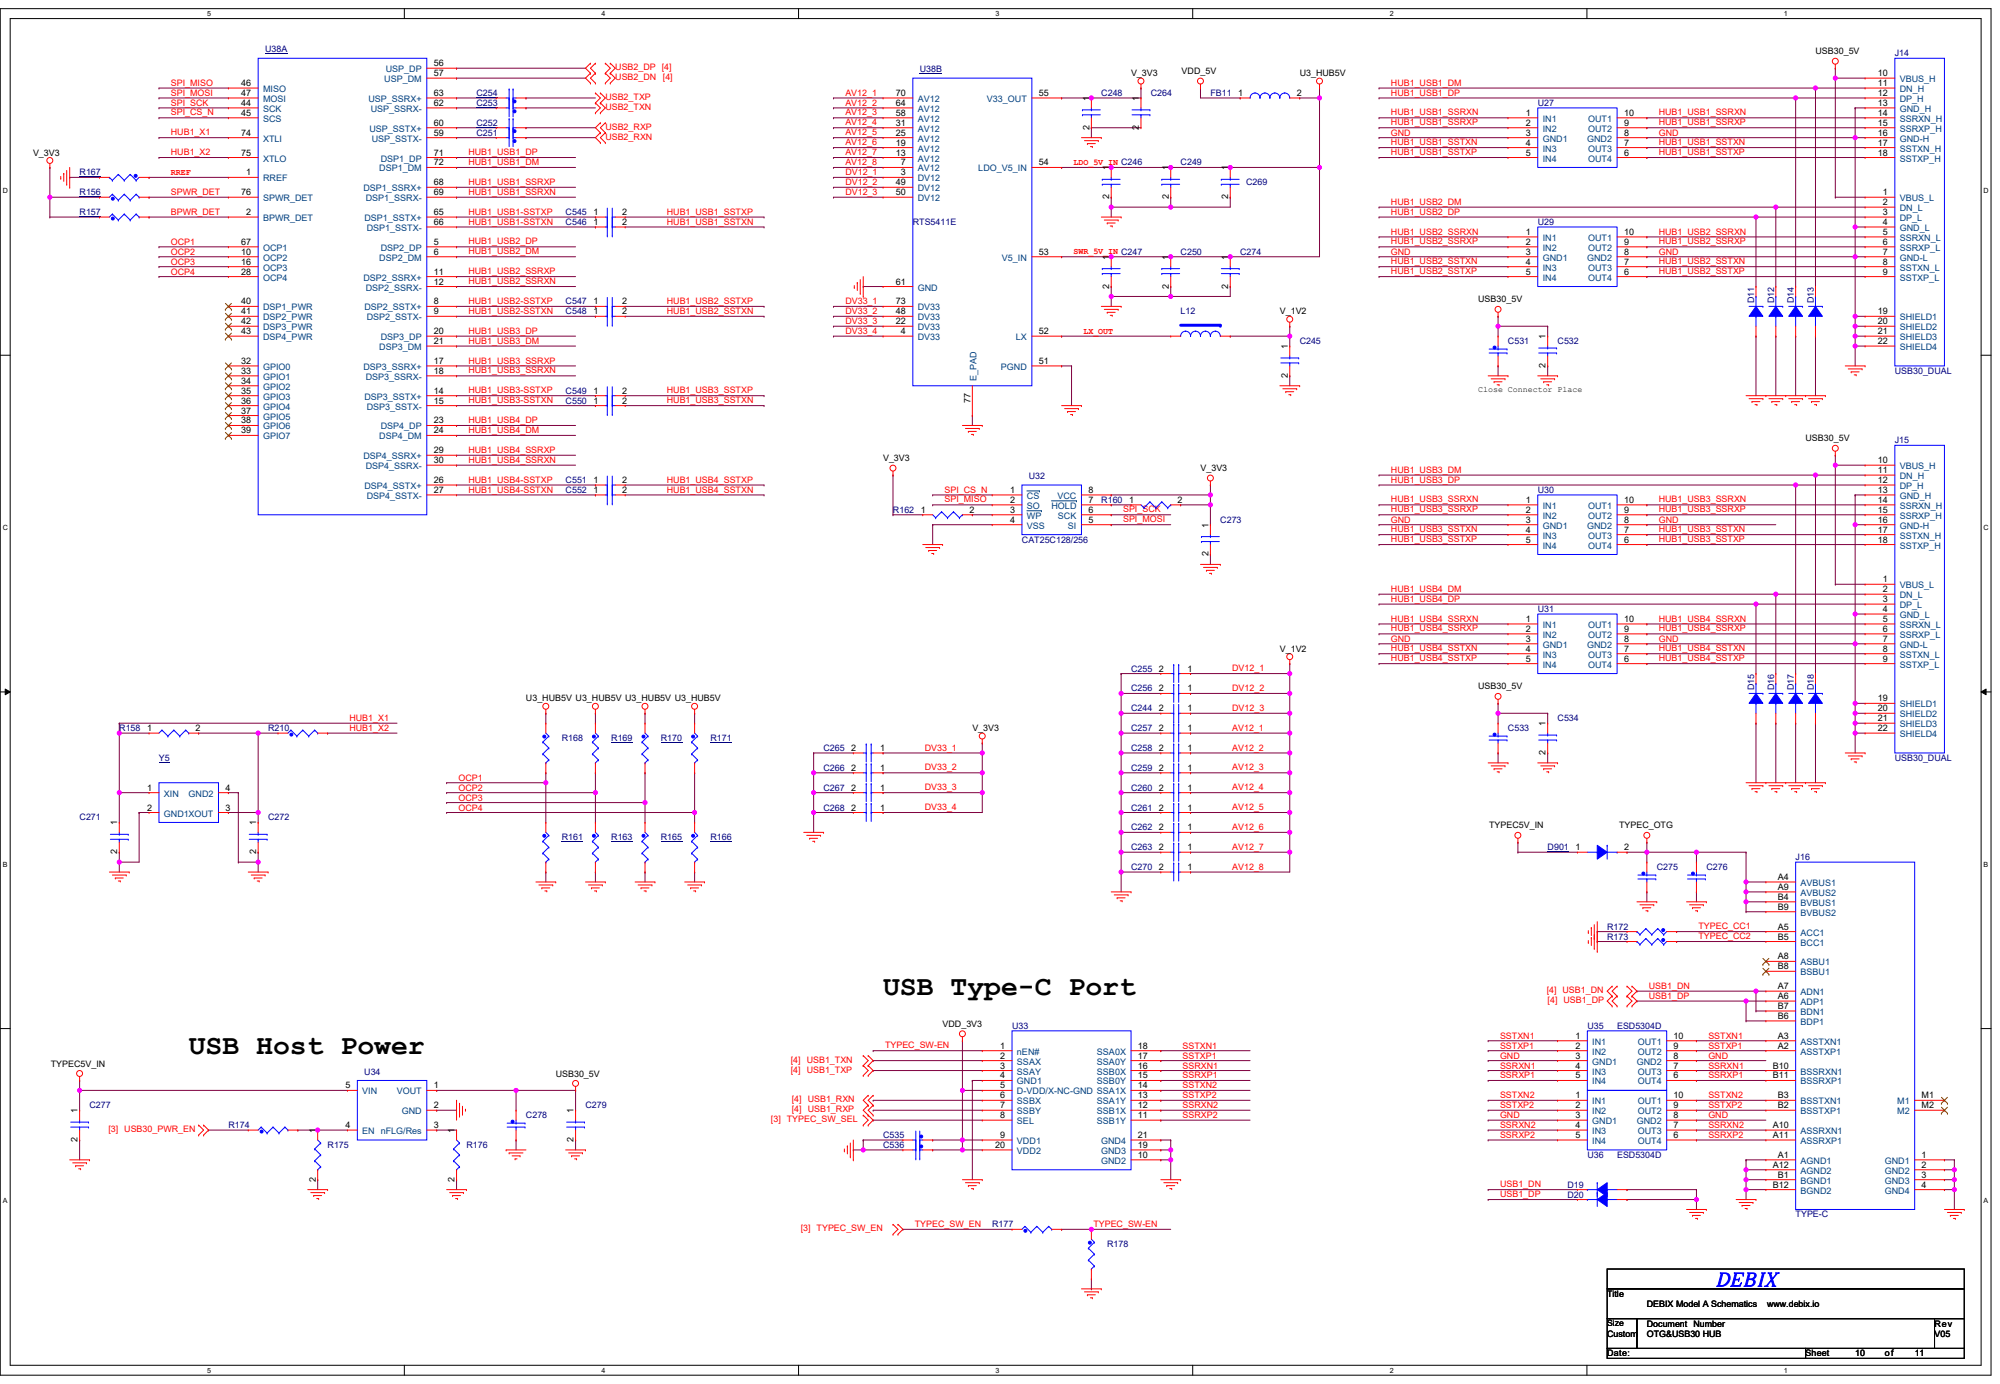
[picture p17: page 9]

D D

# EARPHONE

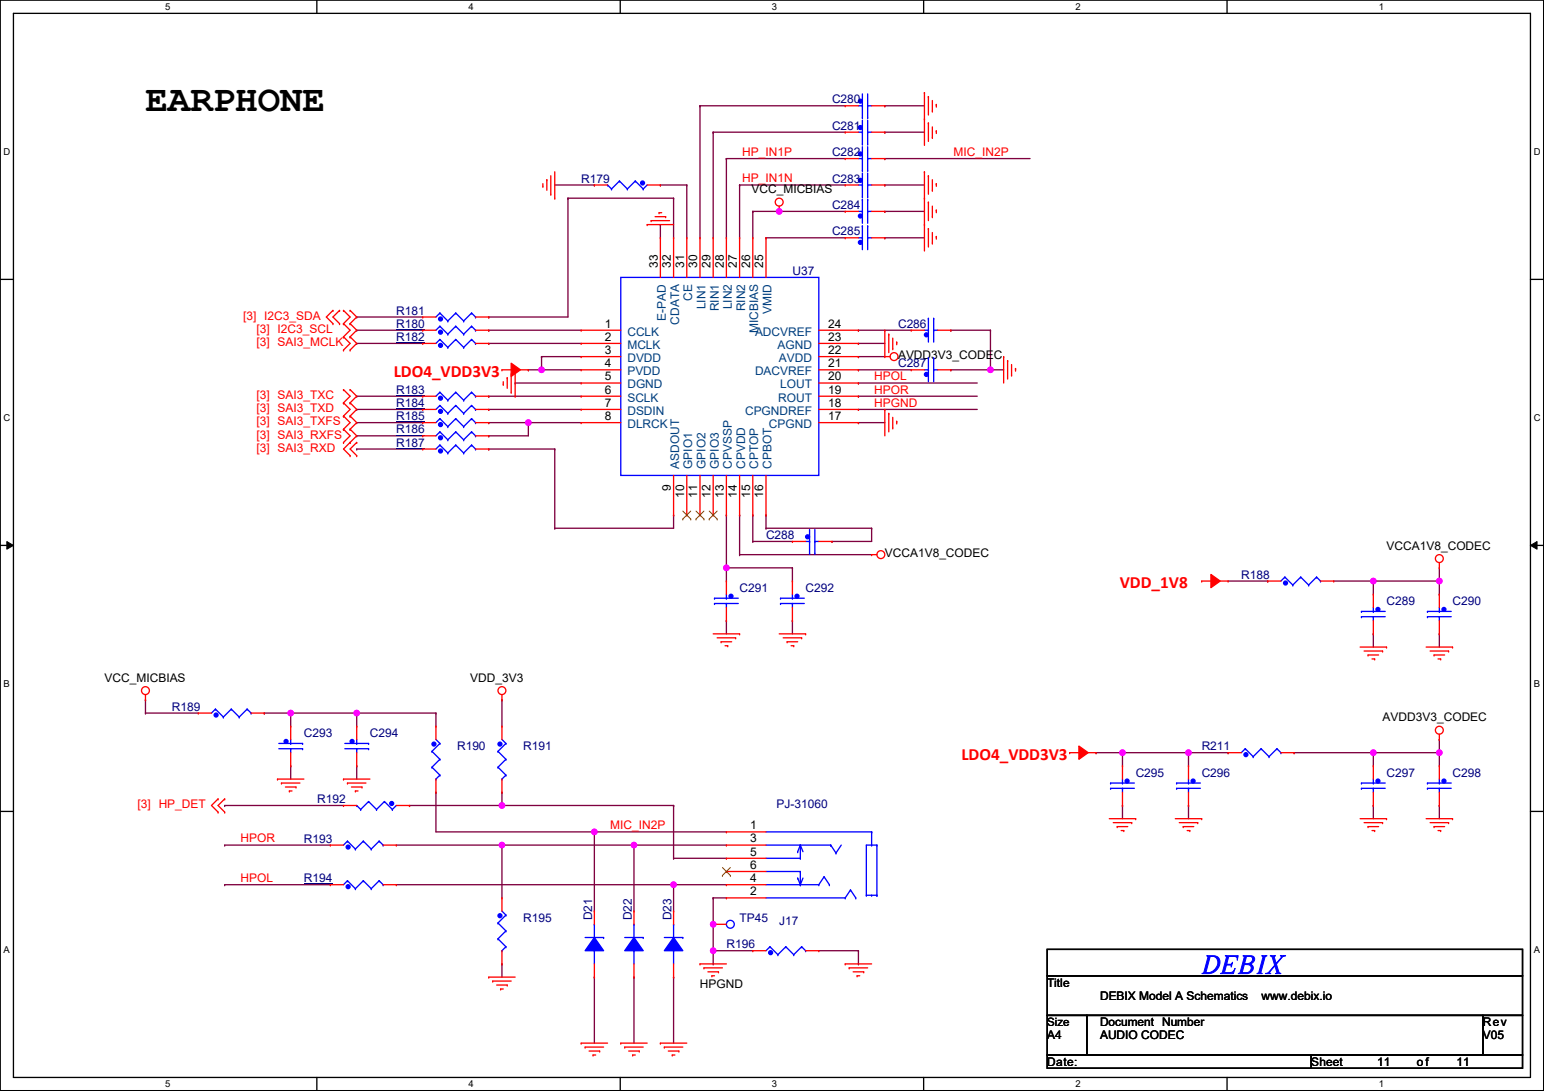
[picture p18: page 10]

DEBIX Model A Schematics www.debix.io

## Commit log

2025-07-11 Reorganize the file structure
    [DEBIX_Model_A_Camera_FPC_24Pin-15Pin_ProductionsDara.PcbDoc, DEBIX_Performance_Test.xlsx, Debix_Model_A_GPIO_Pin_Multiplexing_Function_List_V1.1.xlsx]
2025-07-15 remove DEBIX_Model_A_Camera_FPC PCB
    [DEBIX_Model_A_Camera_FPC_24Pin-15Pin_ProductionsDara.PcbDoc]
2025-07-15 update FPC design files
    [Polyhex 24PIN-Pai 15PIN 0522.GBL, Polyhex 24PIN-Pai 15PIN 0522.GBO, Polyhex 24PIN-Pai 15PIN 0522.GBP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]
